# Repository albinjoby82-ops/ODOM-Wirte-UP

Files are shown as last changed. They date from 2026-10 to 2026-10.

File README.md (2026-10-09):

# ODOM POD Write-Up

The story of the ODOM POD: an ESP32-S3 odometry and localization pod that feeds pose to a VEX V5 brain over an RS-485 link.

This repo holds the narrative write-up. The operations team will turn it into a notebook, so each section is a self-contained, numbered document in `docs/`, meant to be read in order as one story.

## Reading order

| # | Section | Status |
|---|---|---|
| 1 | [Why These Components](docs/01-component-rationale.md) | Done |
| 2 | [What We Built on the Breadboard](docs/02-breadboard-firmware.md) | Done |
| 3 | [PCB V1](docs/03-pcb-v1.md) | Done |
| 4 | [PCB V2](docs/04-pcb-v2.md) | Done |

More sections will be added to this table as the story grows.

## What's in the repo

| Folder | What |
|---|---|
| [`docs/`](docs/) | The write-up, one numbered file per section, with images in `docs/img/` and clips in `docs/media/` |
| [`hardware/`](hardware/) | KiCad design files, Gerbers and PDFs for each PCB version |
| [`code/`](code/) | The pod firmware at each stage: breadboard, PCB V1 and PCB V2 |

## The story in one paragraph

The V5 brain is a good motor controller but a poor sensor platform. The ODOM POD moves sensing and pose estimation onto an ESP32-S3 and sends pose to the V5 as a pure sensor source. Motion control stays on the V5.

## Conventions

- One section per file in `docs/`, named `NN-short-title.md`, so the order is obvious and maps cleanly to notebook sections.
- Legality (VUR12) and latency points are woven into the relevant section, not split out.
- Figures and images go in `docs/img/` when they are added.

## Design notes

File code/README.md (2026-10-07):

# Firmware snapshots

The pod's ESP32-S3 firmware at three points in the project. Each folder is an exact copy of one commit. Nothing has been edited, so the commit hash tells you what you are looking at.

| Folder | Hardware | Commit | Written by |
|---|---|---|---|
| [`breadboard/`](breadboard/) | The breadboard build | `f9613c0` (Sep 12) | Ronan Hawkins |
| [`pcb-v1/`](pcb-v1/) | PCB V1 | `f138950` (Sep 30) | Ronan Hawkins |
| [`pcb-v2/`](pcb-v2/) | PCB V2 | `986a2f3` (Oct 6) | Ronan Hawkins and Albin Joby |

The commits are from [`ODOM-CODE`](https://github.com/albinjoby82-ops/ODOM-CODE), which has the same history as Ronan's [`gaelforce_esp32`](https://github.com/ronanhawkins/gaelforce_esp32). The V2 snapshot is the latest commit in `ODOM-CODE`. [Pull request 1](https://github.com/ronanhawkins/gaelforce_esp32/pull/1) holds the same work up to `d8f95ed`. V2 has not been tested on a built board.

What changed between them is mostly the pin numbers in `include/pod_config.hpp`. The V1 and V2 firmware are not interchangeable, so flash each one only on its own board.

Each folder builds with PlatformIO (ESP-IDF) for the ESP32-S3-DevKitC-1 with the N8R8 module. The shared `gflib` library (odometry, particle filter and link protocol) is not included here, because it is not in either source repo. It is expected next to the project as `../gflib`.

The ToF firmware image in `src/tof_firmware.cpp` comes from SparkFun's Qwiic TMF882X library. The source repos do not have a licence file.

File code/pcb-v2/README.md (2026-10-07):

# Gaelforce ESP32 pod (ODOM V2)

Firmware for an ESP32-S3 sensor pod that works out where the robot is on the
field. It drives nothing: it sends its pose estimate over RS-485 to the Brain.

It combines two quadrature tracking-wheel encoders, a BNO085 IMU and four
TMF8821 distance sensors in a particle filter (`gflib`), and reports the result
100 times a second.

Board: ESP32-S3-DevKitC-1 with an **N8R8** module. Built with PlatformIO and
ESP-IDF.

## Pin map (V2 PCB)

These are the pins the V2 PCB is wired to, and what `include/pod_config.hpp`
and `tools/tof_test` are set to. **8 pins moved from V1** (shown in bold below);
the full list with the reasons is in [PIN_CHANGES.md](PIN_CHANGES.md).

> **V1 and V2 firmware are not interchangeable.** GPIO1, 2 and 4 were encoder
> inputs on V1 and are ToF enable outputs on V2. Flash V2 firmware only on a V2
> board. V1 firmware is commit `f138950`.

| Function | Signal | V2 GPIO | V1 GPIO | Changed |
|---|---|---|---|---|
| Vertical encoder | A | **40** | 1 | yes |
| Vertical encoder | B | **42** | 2 | yes |
| Horizontal encoder | A | **39** | 3 | yes |
| Horizontal encoder | B | **41** | 4 | yes |
| IMU (BNO085) | RX | 8 | 8 | no |
| RS-485 | TX (DI) | 17 | 17 | no |
| RS-485 | RX (RO) | 18 | 18 | no |
| RS-485 | DE + RE (tied) | **7** | 21 | yes |
| ToF I2C | SDA (all 4) | 16 | 16 | no |
| ToF I2C | SCL (all 4) | 15 | 15 | no |
| ToF EN | FRONT | **4** | 11 | yes |
| ToF EN | RIGHT | 12 | 12 | no |
| ToF EN | REAR | **1** | 14 | yes |
| ToF EN | LEFT | **2** | 13 | yes |

Free for future use: 3 (strapping pin), 5, 6, 9, 10, 11, 13, 14, 21, 38.

### Pins that must not be used

On an N8R8 module:

| GPIO | Reason |
|---|---|
| 0, 45, 46 | strapping pins |
| 19, 20 | native USB (flashing and serial monitor) |
| 26-32 | SPI flash |
| 33-37 | octal PSRAM, wired inside the module even though this project leaves PSRAM off |
| 43, 44 | console UART |
| 48 | on-board RGB LED |

This is why the encoders went to 39-42 and not 35-38: 35, 36 and 37 are the
PSRAM pins.

## Wiring

### Encoders (via SN74LVC245A level converter)

The encoders connect to the A side of the converter and the ESP32 to the B side
(DIR tied high, OE to GND, VCC to 3.3 V). Each signal passes straight across
(A1 to B1 and so on). The B pins are arranged so the wiring is easy, not in the
order the firmware names them:

| Converter pin | Encoder wire | ESP32 GPIO |
|---|---|---|
| B1 | Vertical **B** | 42 |
| B2 | Horizontal **B** | 41 |
| B3 | Vertical **A** | 40 |
| B4 | Horizontal **A** | 39 |

Tie unused converter inputs to GND. If an encoder counts backwards, flip its
`kVertReversed` / `kHorizReversed` flag in `pod_config.hpp` rather than
rewiring.

### IMU (BNO085, UART-RVC mode)

| IMU pin | Connects to |
|---|---|
| SDA (becomes the IMU's serial TX in UART mode) | GPIO8 |
| SCL | nothing |
| VIN | 3.3 V |
| GND | GND |

The **P0 jumper must be bridged** to select UART-RVC mode. Without it the IMU
starts in I2C mode and GPIO8 never receives anything.

### RS-485 link to the Brain (SP3485)

| SP3485 pin | Connects to |
|---|---|
| DI | GPIO17 |
| RO | GPIO18 |
| DE and RE, tied together | GPIO7 |
| VCC / GND | 3.3 V / GND |
| A, B | the Brain's A, B |

Run a **ground wire** to the Brain alongside A and B. If the link only receives
garbage, A and B are probably swapped. DE is the talk/listen switch: the ESP32
switches it automatically around each message, so it must not be shared with
anything else.

### ToF sensors (4x TMF8821)

All four share SDA and SCL, are powered from **3.3 V**, and each has its own EN
pin because they all start at the same I2C address and are brought up one at a
time. Leave INT, GPIO0 and GPIO1 on the sensor boards unconnected.

The breakouts' own pull-up resistors are the only pull-ups on the bus, so at
least one breakout's I2C pull-up jumper must be closed.

## Changing a pin

Every pin lives in `include/pod_config.hpp`. The ToF bench test keeps its own
copy of the ToF pins in `tools/tof_test/src/main.cpp`, so change both. See
[PIN_CHANGES.md](PIN_CHANGES.md) for the history of each move.

## Bench test for the ToF sensors

`tools/tof_test` is a standalone project that brings up the four sensors with
the pod's own driver and prints one distance per sensor. It does not need
`gflib`.

```bash
pio run -d tools/tof_test -t upload -t monitor
```

It prints `FRONT`, `RIGHT`, `REAR` and `LEFT` distances in mm. `--` means
nothing is in range, `DEAD` means a sensor failed to start, and `STALLED` means
it stopped sending results. A reading that sticks at 20-60 mm and never changes
means something is right against the lens.

## Building the pod firmware

The pod firmware needs `gflib` (particle filter, odometry and link framing)
cloned next to this repo at `../gflib`; it is not in this repository.

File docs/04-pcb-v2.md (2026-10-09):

# PCB V2

V2 fixes what went wrong with V1. It has two changes: a fixed IMU ground, and a pin map that follows where the cables leave the board.

## What changed

**The IMU ground.** On V1, the ground trace for the IMU was on the top layer when it should have been on the bottom. V2 has it on the bottom layer.

**The pins.** V1 kept the breadboard's pin numbers, which left the encoder and ToF cables scattered around the board. V2 regroups the pins so each set of cables leaves from one place. Eight pins moved. Everything else is the same.

| Signal | V1 GPIO | V2 GPIO | Why |
|---|---|---|---|
| Vertical encoder A | 1 | **40** | Encoders grouped on four adjacent header pins |
| Vertical encoder B | 2 | **42** | |
| Horizontal encoder A | 3 | **39** | |
| Horizontal encoder B | 4 | **41** | |
| ToF enable, front | 11 | **4** | Uses a pin the encoders freed up |
| ToF enable, rear | 14 | **1** | Uses a pin the encoders freed up |
| ToF enable, left | 13 | **2** | Uses a pin the encoders freed up |
| RS-485 DE/RE | 21 | **7** | Nearest free pin that is not a strapping pin |

These stay the same: the IMU receive pin on GPIO 8, RS-485 TX and RX on 17 and 18, I²C SDA and SCL on 16 and 15, and the right ToF enable on 12.

The level converter's B pins are also wired to make the cabling easier. B1 and B2 carry the encoders' B channels, and B3 and B4 carry their A channels. If an encoder counts backwards, the firmware has a reverse flag for each one, so the wiring does not need to change.

The full write-up of every move, with the reason for each, is in [`PIN_CHANGES.md`](../code/pcb-v2/PIN_CHANGES.md), and the V2 wiring tables are in the [firmware README](../code/pcb-v2/README.md).

## The V2 firmware

The V2 firmware is the V1 firmware with the new pin numbers in `include/pod_config.hpp`, plus the later ToF mask-order fix and bench test. It is in [`code/pcb-v2/`](../code/pcb-v2/), at commit `986a2f3` of `ODOM-CODE`.

V1 and V2 firmware are not interchangeable. GPIO 1, 2 and 4 were encoder inputs on V1 and are ToF enable outputs on V2, so flashing the wrong firmware drives the wrong wire. Flash V2 firmware only on a V2 board.

## Status

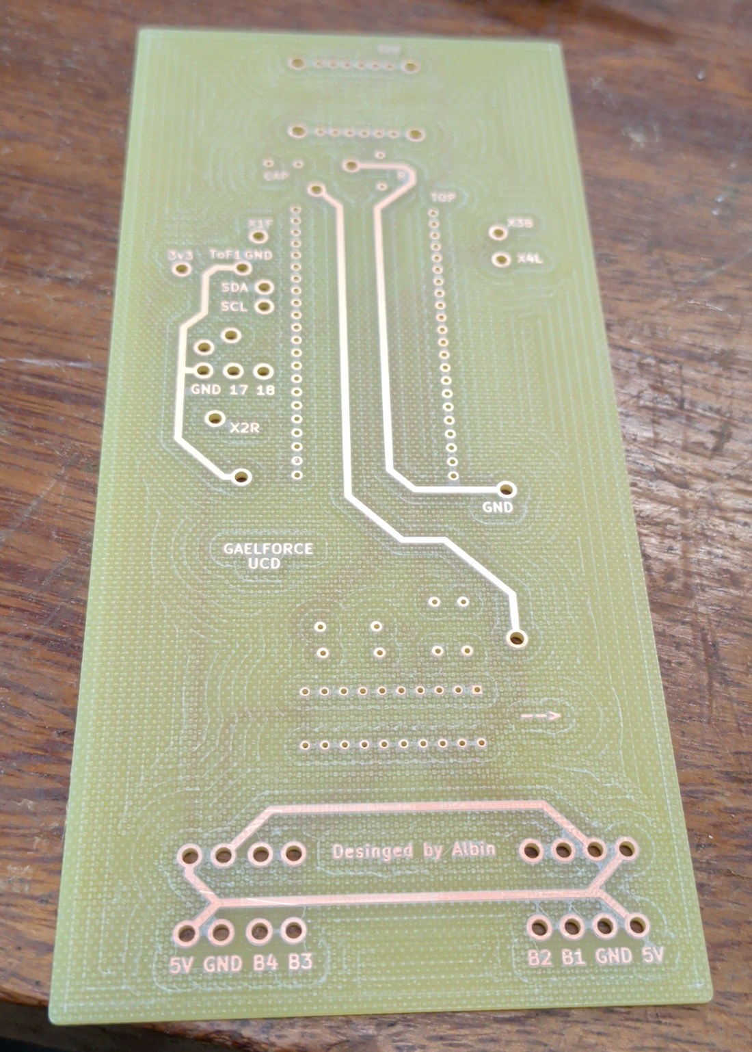
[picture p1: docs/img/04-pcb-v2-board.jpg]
The bare V2 board, a tall narrow green board with white copper traces and silkscreen labels such as 5V, GND, B4 and B3 along the bottom


The V2 board right after it came off the machine at the Elecworkshop.

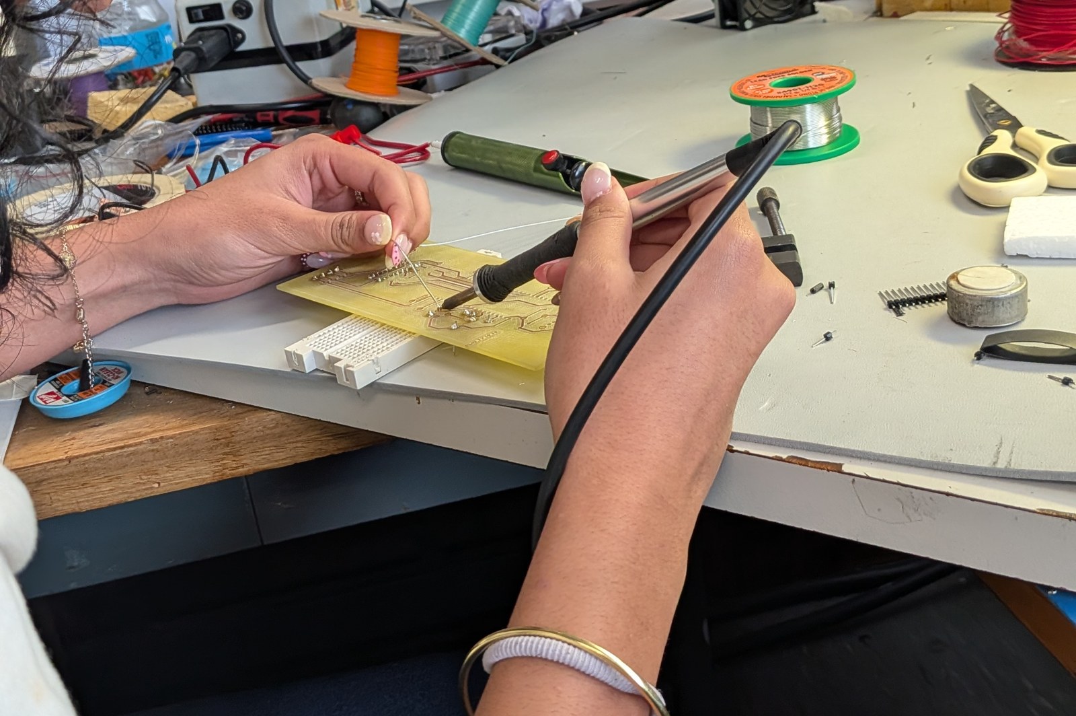
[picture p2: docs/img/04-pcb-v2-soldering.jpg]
Two people soldering parts onto a V2 board held on a breadboard strip, one holding a part in place and the other using a soldering iron


Soldering the V2 board with Selma. The board is now soldered and finished. It is waiting to be tested, so there are no results here.

## Design files

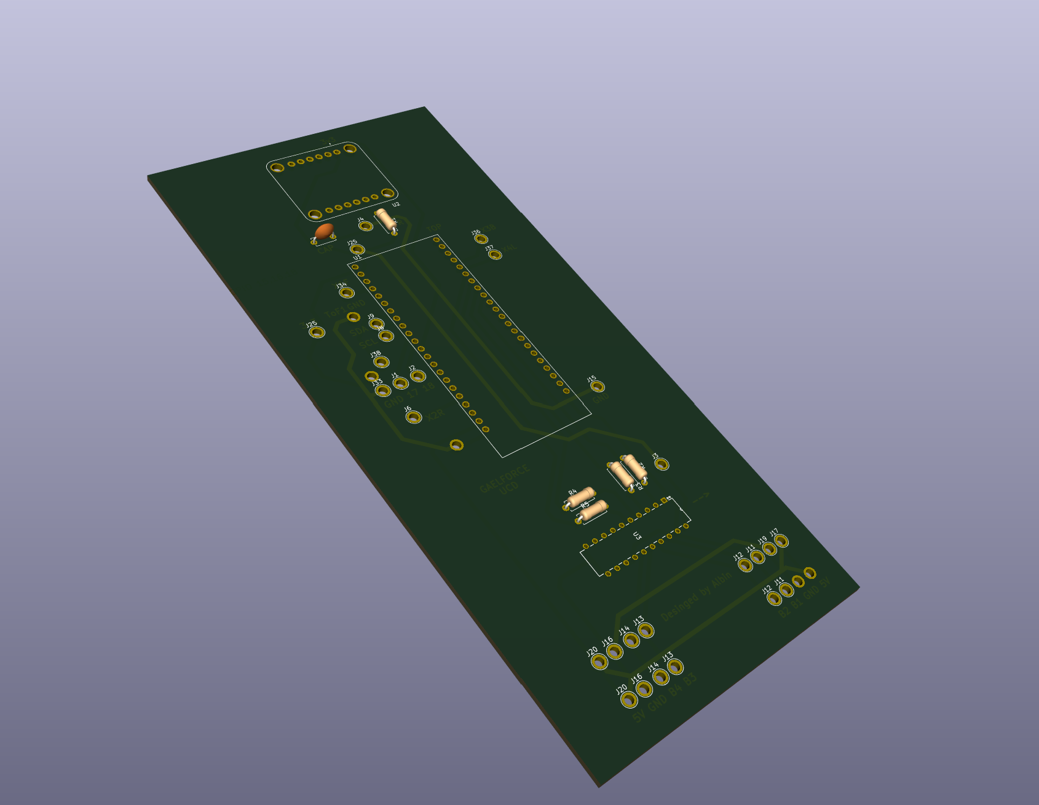
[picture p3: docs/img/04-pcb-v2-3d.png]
A 3D render of the V2 board from KiCad: a tall green board with the IMU breakout outline at the top, the ESP32-S3 outline in the middle, four resistors and the level converter below it, and rows of single-pin connectors at the bottom and along the sides


A 3D render of the V2 board from KiCad. The board is long and narrow. The IMU breakout is at the top, the ESP32-S3 is in the middle, and the four resistors and the level converter are below it. The ESP32-S3 and the IMU show only as outlines, because their 3D models are not in the project.

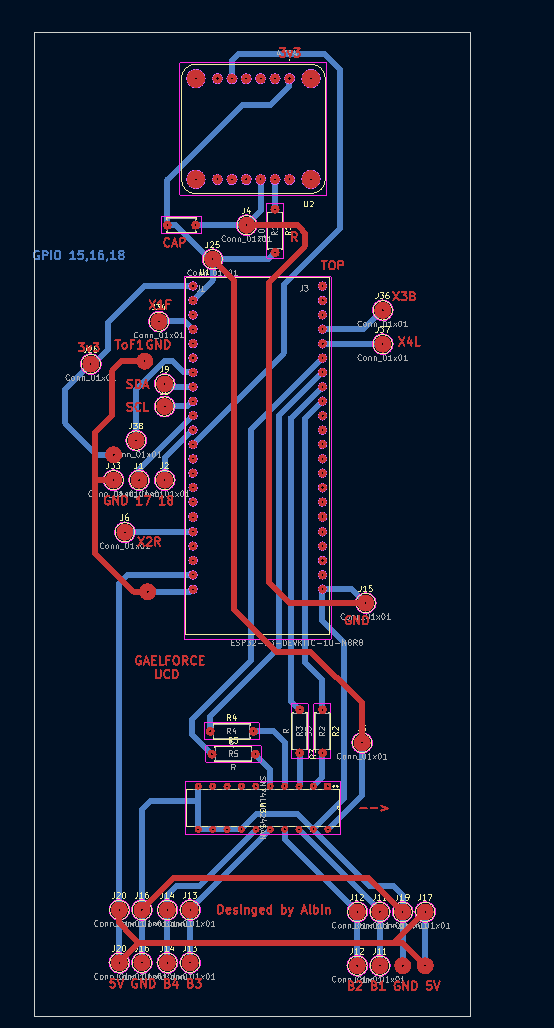
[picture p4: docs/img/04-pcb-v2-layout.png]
The V2 board layout in KiCad, front copper in red and back copper in blue, with traces running from the ESP32-S3 pins to single-pin connectors at the bottom and along the sides


The V2 board layout, from the KiCad PCB editor. Front copper is red and back copper is blue. Traces run from the ESP32-S3 pins and the level converter to the single-pin connectors at the bottom and along the sides. Click the image for the PDF.

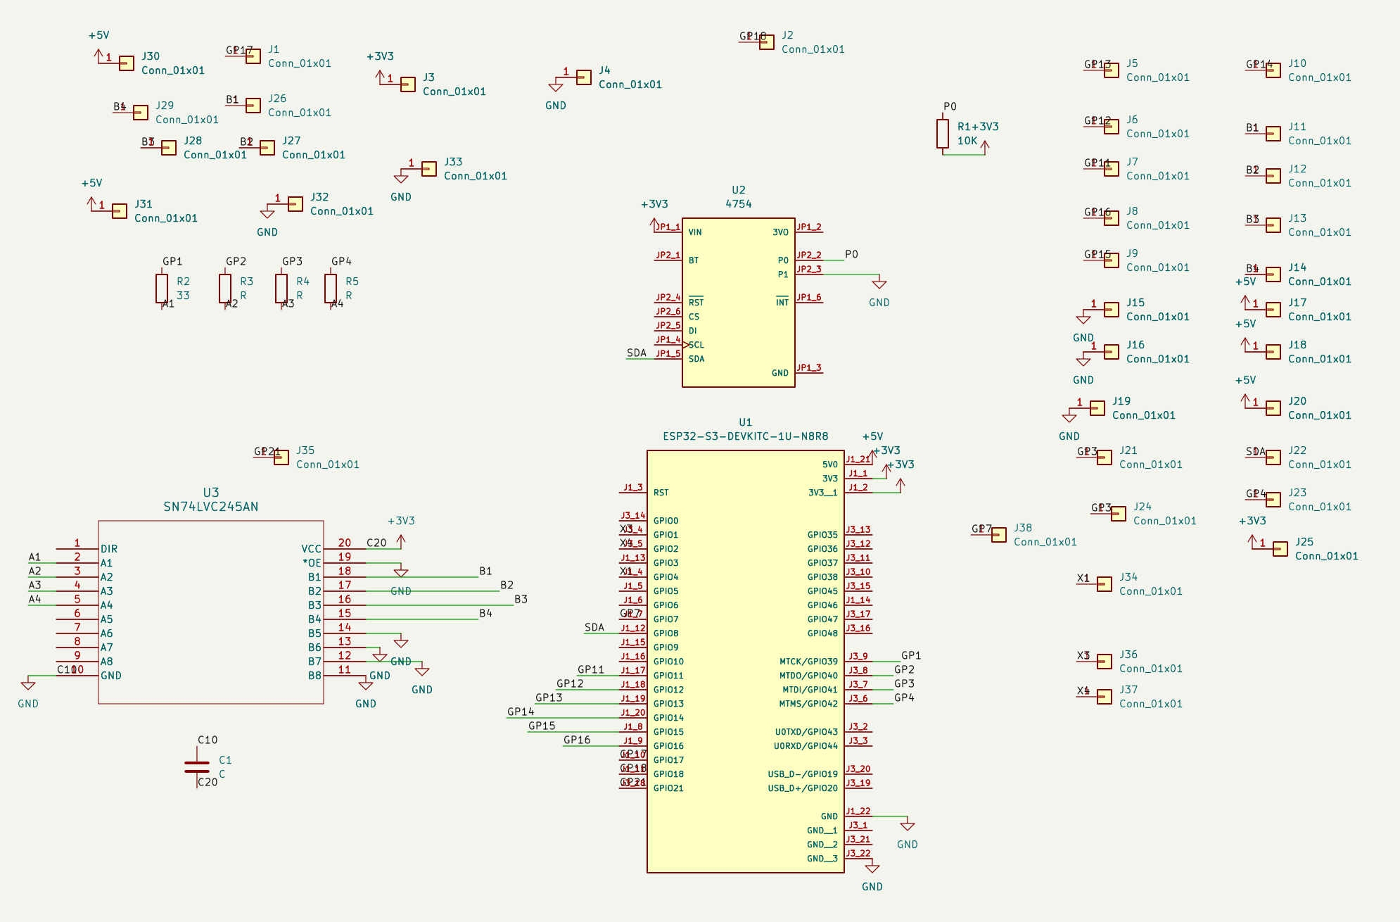
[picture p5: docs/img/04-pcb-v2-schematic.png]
The V2 schematic: the ESP32-S3 dev board, the IMU breakout, the level converter with four resistors, and a column of single-pin connectors on the right


The V2 schematic. It has the ESP32-S3 dev board, the IMU breakout, the level converter and four resistors, and a single-pin connector for each off-board wire. Click the image for the PDF.

- [Schematic (PDF)](../hardware/v2/ODOM-V2-schematic.pdf)
- [PCB layout (PDF)](../hardware/v2/ODOM-V2-pcb-layout.pdf)
- [Gerbers and drill files](../hardware/v2/gerbers.zip), as sent to the board maker. The [job file](../hardware/v2/ODOM%20V2-job.gbrjob) is next to it.
- [KiCad project folder](../hardware/v2/): the schematic, board file, project file and custom symbol and footprint libraries.

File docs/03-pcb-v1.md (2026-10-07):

# PCB V1

## The idea

The breadboard worked, so the first PCB was a direct copy of it: the same schematic, the same parts and the same connections, laid out on a board. The schematic and the PCB were designed in KiCad, the board was made in the Elecworkshop, and the parts were soldered on.

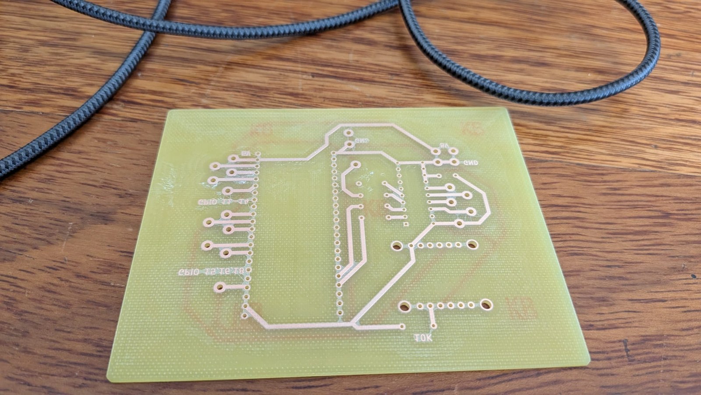
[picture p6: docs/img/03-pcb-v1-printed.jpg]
The bare V1 board after it was made, copper side, with the pin labels printed mirrored


The bare V1 board, copper side.

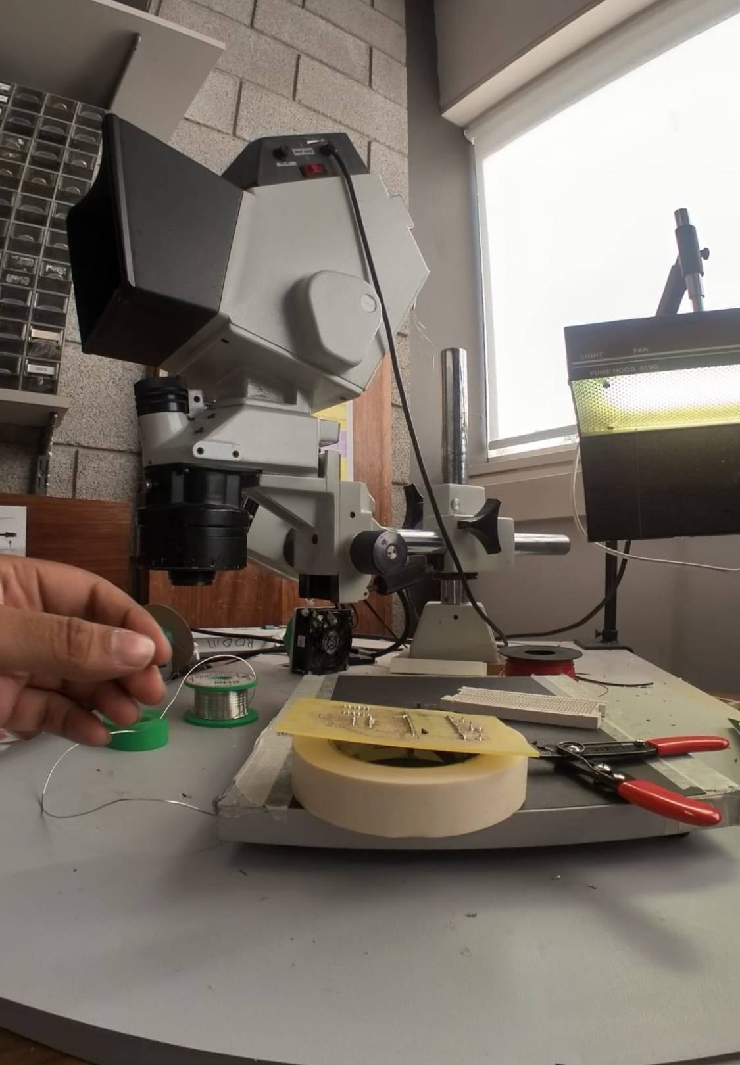
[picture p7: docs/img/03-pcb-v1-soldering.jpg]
Soldering parts onto the V1 board at a workbench with a microscope, solder and wire cutters


Soldering the V1 board.

## What went wrong

On a breadboard, any signal can go to any pin, because you just plug in a jumper wire. On a PCB that freedom is gone, and the wiring that matters is the wiring that leaves the board. Both encoders and all four ToF sensors connect to the pod by cables, so every one of those cables had to leave the board somewhere.

The pin assignments came straight from the breadboard, where they had been chosen for convenience, so on the PCB they ended up scattered across the ESP32's headers. The cables coming off the board for the encoders and the ToF sensors were a tangled mess.

Copying the breadboard exactly turned out not to be the right way to get a PCB. A good PCB layout starts from where the connectors and cables go, and picks the pins to suit.

## What worked

The board worked. The ToF sensors and the rest of the pod ran the V1 firmware. There was one layout mistake: the ground trace for the IMU was on the top layer when it should have been on the bottom. V2 fixes it.

## The V1 firmware

The V1 firmware is Ronan's `gaelforce_esp32` at commit [`f138950`](https://github.com/albinjoby82-ops/ODOM-CODE/tree/f138950) (Sep 30, "pin changes"). A copy is in this repo at [`code/pcb-v1/`](../code/pcb-v1/). It differs from the breadboard firmware in the pin numbers only. Two signals moved: the horizontal encoder from GPIO 4/5 to GPIO 3/4, and the ToF I²C pins from SDA/SCL 15/16 to 16/15.

| Function | Signal | GPIO |
|---|---|---|
| Vertical encoder | A / B | 1 / 2 |
| Horizontal encoder | A / B | 3 / 4 |
| IMU (BNO085) | RX | 8 |
| RS-485 | TX / RX / DE+RE | 17 / 18 / 21 |
| ToF I²C | SDA / SCL | 16 / 15 |
| ToF enable | Front / Right / Rear / Left | 11 / 12 / 14 / 13 |

## What it taught us

The problem was never the parts or the schematic. It was the pin layout. That led to V2, which starts from where the cables leave the board and groups the pins to match.

## Design files

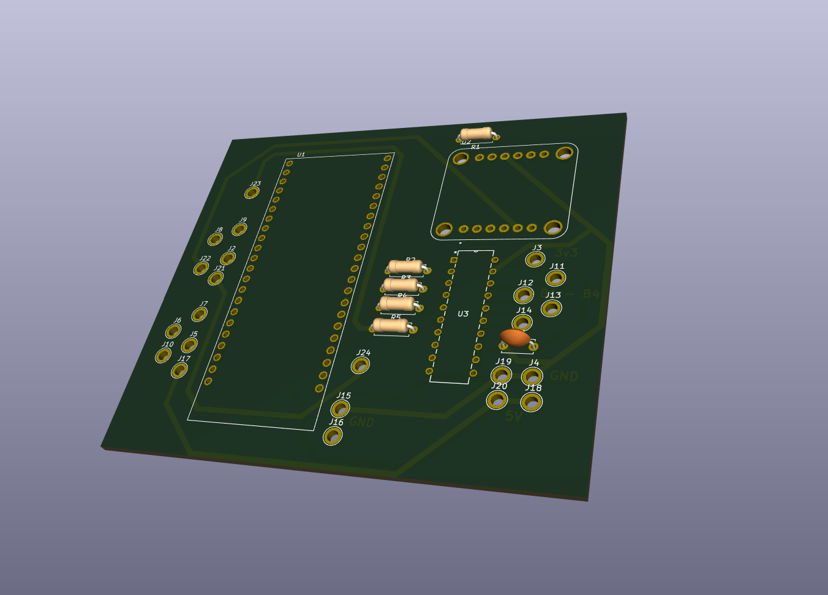
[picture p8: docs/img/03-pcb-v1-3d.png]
A 3D render of the V1 board from KiCad: the ESP32-S3 dev board footprint on the left, the IMU breakout at the top right, the level converter and four resistors in the middle, and single-pin connectors around the edges


A 3D render of the V1 board from KiCad. The ESP32-S3 dev board sits on the left, the IMU breakout at the top right, and the level converter and the four series resistors in the middle. The single-pin connectors are scattered around the edges and the corners.

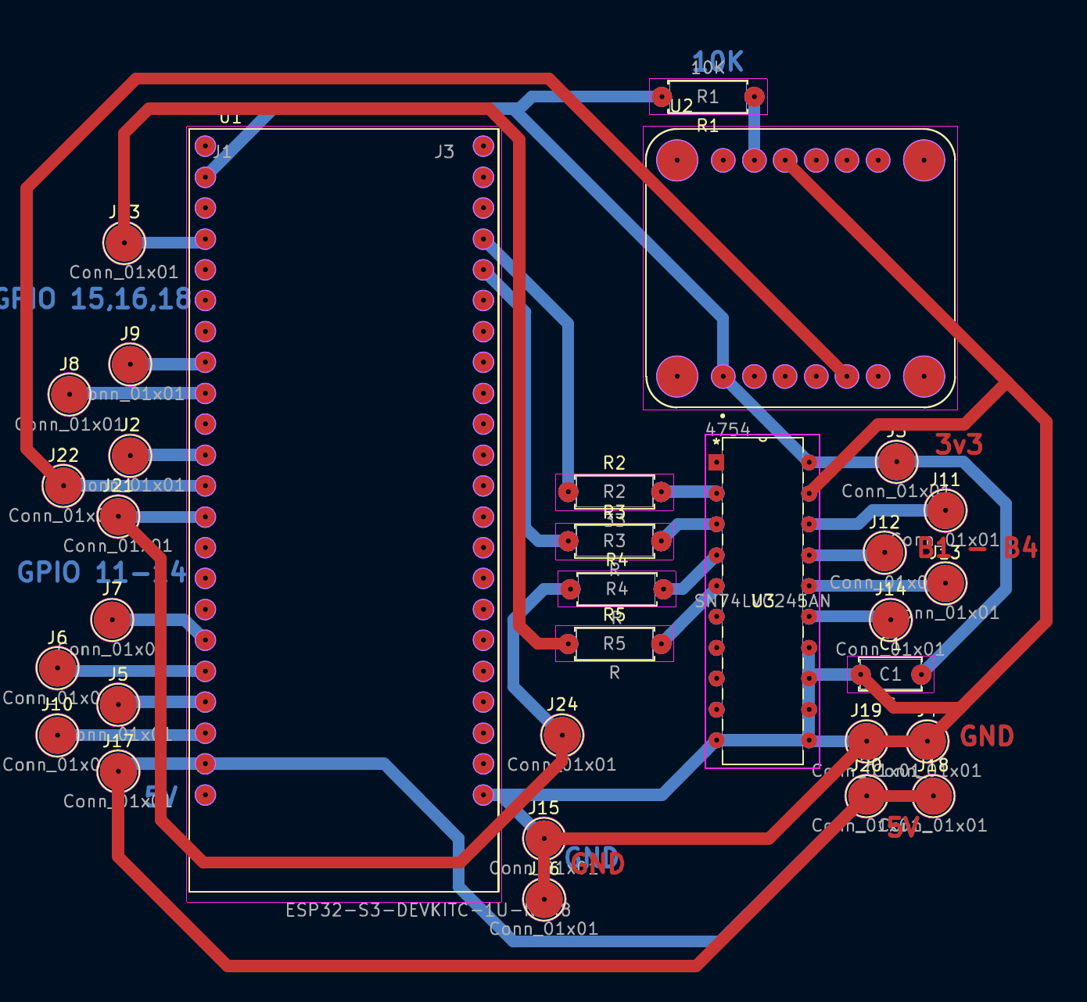
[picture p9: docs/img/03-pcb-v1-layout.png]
The V1 board layout in KiCad, front copper in red and back copper in blue, with traces from the ESP32-S3 pins running out to single-pin connectors around the edges


The V1 board layout, from the KiCad PCB editor. Front copper is red and back copper is blue. The traces fan out from the ESP32-S3's pins to the single-pin connectors around the edges. Click the image for the PDF.

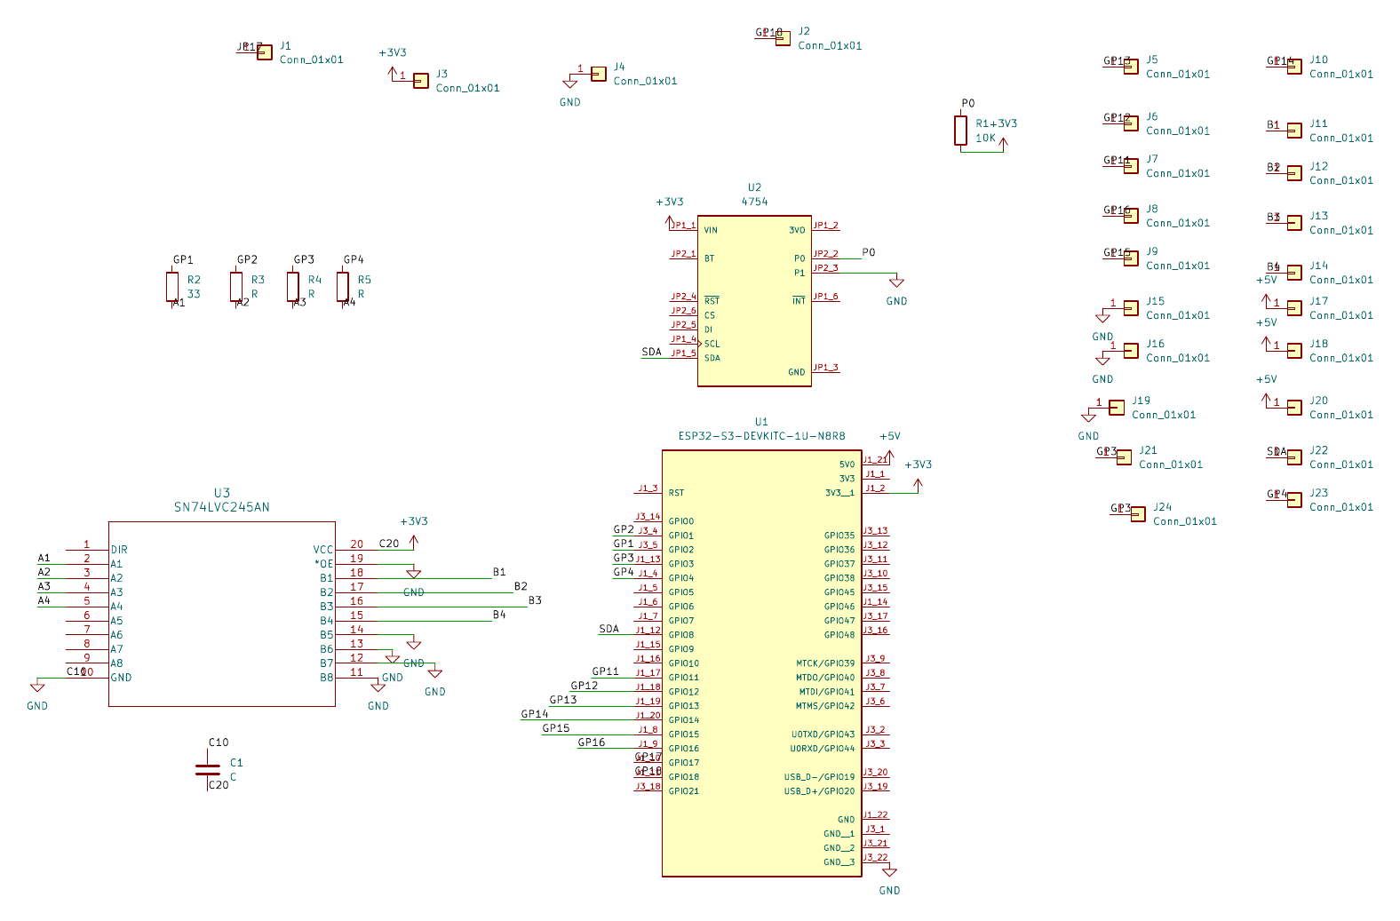
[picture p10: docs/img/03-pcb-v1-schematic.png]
The V1 schematic: the ESP32-S3 dev board, a level converter with series resistors on the four encoder lines, the IMU breakout, and single-pin connectors for the off-board wires


The V1 schematic. It has the ESP32-S3 dev board, the level converter with series resistors on the four encoder lines, the IMU breakout, and a single-pin connector for each off-board wire. Click the image for the PDF.

- [Schematic (PDF)](../hardware/v1/ODOM-V1-schematic.pdf)
- [PCB layout (PDF)](../hardware/v1/ODOM-V1-pcb-layout.pdf)
- [Gerbers and drill files](../hardware/v1/gerbers.zip), as sent to the board maker.
- [KiCad project folder](../hardware/v1/): the schematic, project file and custom symbol and footprint libraries.

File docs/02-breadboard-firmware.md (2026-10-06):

# What We Built on the Breadboard

When the parts arrived, we wired every component from section 1 onto a breadboard and flashed one firmware image to the ESP32-S3.

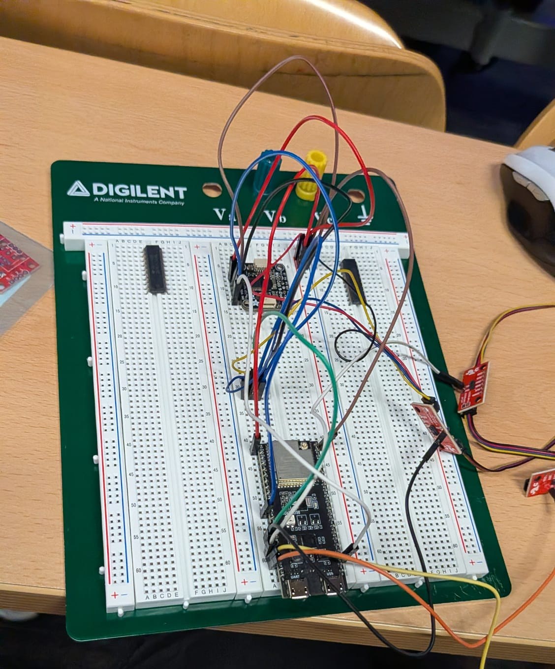
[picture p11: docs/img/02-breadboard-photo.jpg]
The breadboard: an ESP32-S3 dev board in the centre, a level converter and the BNO085 across the top, and ToF sensors on Qwiic cables off the right edge


The breadboard build. The ToF sensors sit off the board on their Qwiic cables.

## What it does

The firmware reads the two AMT102-V encoders (through the level converter), the BNO085 IMU, and the four TMF8821 ToF sensors. It runs a 300-particle Monte Carlo localization filter and sends the resulting pose to the V5 brain over RS-485 every 10 ms (100 Hz). The brain replies with its status, and the pod uses that reply to measure round-trip time and to stop trusting ToF readings while the robot is driving hard. The pod drives nothing. It only reports pose.

Everything runs in a single task, and the firmware prints its own timing, link and per-sensor diagnostics about once a second.

## Pin map (breadboard)

| Function | Signal | GPIO |
|---|---|---|
| Vertical encoder | A | 1 |
| Vertical encoder | B | 2 |
| Horizontal encoder | A | 4 |
| Horizontal encoder | B | 5 |
| IMU (BNO085, UART-RVC) | RX | 8 |
| RS-485 | TX (DI) | 17 |
| RS-485 | RX (RO) | 18 |
| RS-485 | DE + RE (tied) | 21 |
| ToF I²C (all 4 sensors) | SDA | 15 |
| ToF I²C (all 4 sensors) | SCL | 16 |
| ToF enable | Front | 11 |
| ToF enable | Right | 12 |
| ToF enable | Rear | 14 |
| ToF enable | Left | 13 |
| Console UART | TX / RX | 43 / 44 (921600 baud) |

Notes on the wiring:
- The encoders' 5 V outputs go through the SN74LVC245A level converter to reach 3.3 V logic.
- The SP3485 RS-485 transceiver has DE and RE tied together and driven as the UART's RTS pin, so the hardware handles the send/receive turnaround.
- The BNO085 is receive-only. Its P0 jumper must be bridged to select UART-RVC mode, otherwise it starts in I²C mode and the RX pin stays silent.
- The four ToF sensors share one I²C bus. They all boot at address `0x41`, so each has its own enable pin and is moved to `0x42` (front), `0x43` (right), `0x44` (rear) or `0x45` (left) one at a time at boot.
- The ToF enable pins are in harness order, not numeric order.
- GPIO 0/45/46, 19/20, 26-37 and 48 are not used on this module (strapping, USB, flash, PSRAM and the on-board LED).

## Circuit diagrams

The breadboard was wired from these four diagrams.

### Encoders

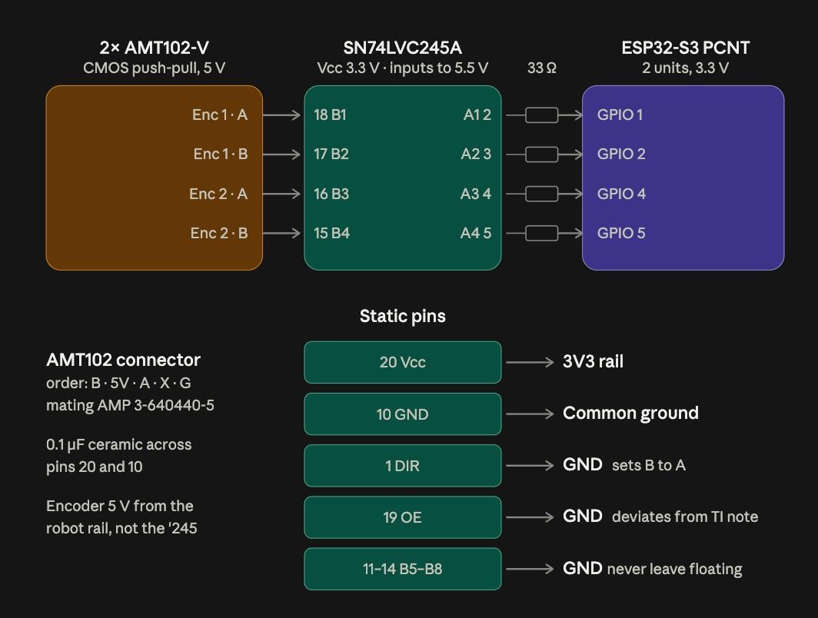
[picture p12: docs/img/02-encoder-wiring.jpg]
Two AMT102-V encoders into an SN74LVC245A level converter, through 33 ohm resistors, to four ESP32-S3 GPIOs


The 5 V encoder outputs go through the SN74LVC245A to 3.3 V logic, with a 33 Ω resistor in each line. The encoders get their 5 V from the robot rail, not from the level converter. The unused B5-B8 inputs are tied to ground, and OE is tied low.

### IMU

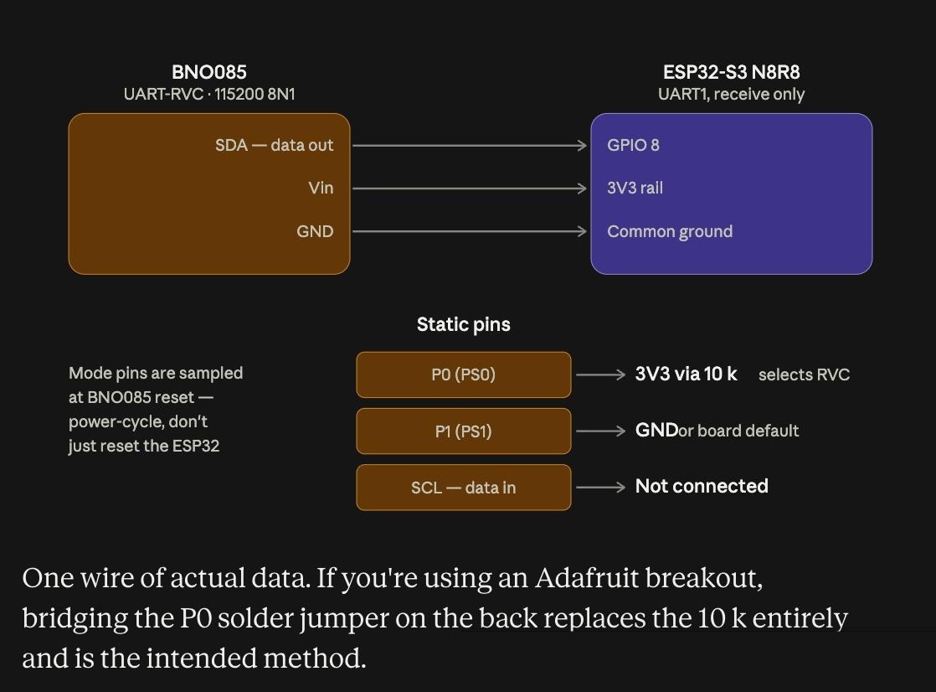
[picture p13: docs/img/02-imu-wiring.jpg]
BNO085 in UART-RVC mode wired to ESP32-S3 GPIO 8, with its mode pins tied off


One data wire from the BNO085 to GPIO 8, plus power and ground. P0 selects RVC mode, so it is tied to 3.3 V, or bridged with the solder jumper on the back of the Adafruit breakout. The mode pins are only read at reset, so the BNO085 has to be power-cycled, not just the ESP32.

### ToF sensors

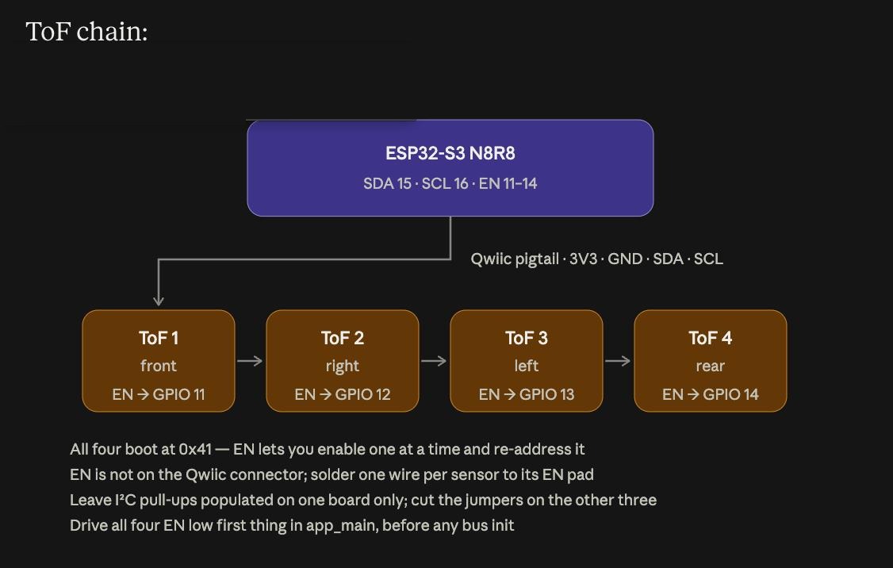
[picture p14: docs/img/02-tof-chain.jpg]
Four TMF8821 sensors daisy-chained over Qwiic from the ESP32-S3, each with its own enable line


Four TMF8821s on one Qwiic chain, each with its own enable wire (front, right, left, rear on GPIO 11, 12, 13, 14). All four boot at `0x41`, so they are enabled one at a time and given new addresses. The enable pin is not on the Qwiic connector, so one wire is soldered to each sensor's EN pad. I²C pull-ups are left on for one board only. All four sensors worked on the breadboard with this firmware.

### RS-485 link

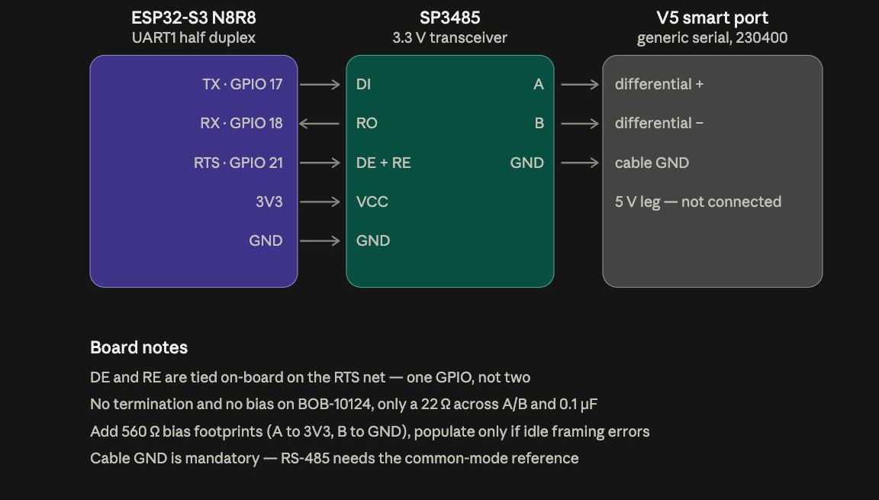
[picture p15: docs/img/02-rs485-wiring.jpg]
ESP32-S3 to SP3485 transceiver to the V5 smart port, with board notes on termination and bias


The ESP32's UART drives an SP3485 transceiver, which connects to the V5 smart port's two differential lines. The 5 V line on the smart port is not connected, but the cable ground is, because RS-485 needs the common reference.

### Working on it

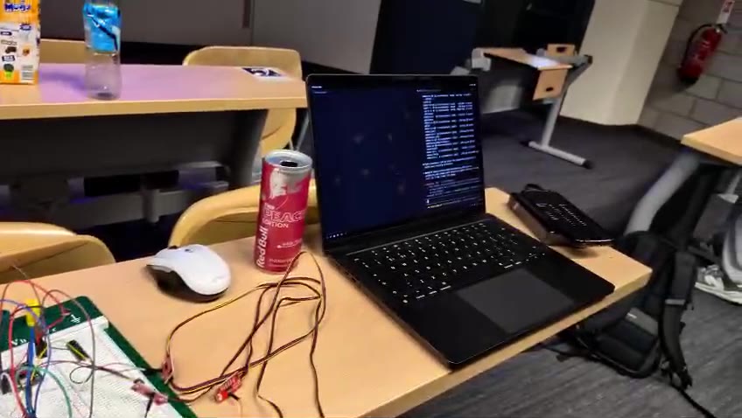
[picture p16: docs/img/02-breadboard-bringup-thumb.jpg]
Firmware console output on the laptop beside the breadboard


A 5-second clip of the breadboard being worked on, with the firmware's console output on the laptop. Click the image to play it.

## Key settings

| Setting | Value |
|---|---|
| Encoder resolution | 8192 counts per revolution (AMT102-V at 2048 PPR, all four edges counted) |
| Encoder glitch filter | 1 µs |
| Pod mounting | Diamond, 45° |
| IMU link | 115200 baud, 19-byte frames |
| Loop rate | 10 ms (100 Hz) |
| ToF I²C speed | 100 kHz to set up, 400 kHz to run |
| ToF ranging | 70 ms period, staggered 17 ms between sensors, custom 4-zone map |
| Particle filter | 300 particles |
| Pose report | 56 bytes from the pod, 23-byte status reply from the brain |

## The code we flashed

| What | Where |
|---|---|
| Firmware | [`ODOM-CODE` at `f9613c0`](https://github.com/albinjoby82-ops/ODOM-CODE/tree/f9613c0) (Ronan Hawkins, Sep 12) |
| Same code, original repo | [`gaelforce_esp32` at `f9613c0`](https://github.com/ronanhawkins/gaelforce_esp32/tree/f9613c0) |
| Copy in this repo | [`code/breadboard/`](../code/breadboard/) |
| Pin numbers | `include/pod_config.hpp` |
| Main loop | `src/main.cpp` |
| ToF bring-up and filtering | `src/tof_array.cpp` |
| ToF SPAD mask | `tools/tmf8x2x_gaelforce_mask.c` |

Build with PlatformIO (ESP-IDF) for the ESP32-S3-DevKitC-1 with the N8R8 module. The shared `gflib` library (odometry, particle filter, link protocol) is not in either repo.

Later commits are not part of the breadboard build. `f138950` (Sep 30) moved the pins, `5a9fc94` (Oct 1) fixed the ToF mask download order and added a ToF bench test, and the V2 PCB rework came after that.

## How it differs from section 1

Section 1 is the design intent. The breadboard build runs as one task at 100 Hz rather than the two-core split, leaves PSRAM off, and gives the filter one median distance per ToF sensor rather than a distance-and-angle pair.

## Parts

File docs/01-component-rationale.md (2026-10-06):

# Why These Components

## The Core Decision: Sensing on an ESP32-S3, Motion Control on the V5

Every choice in this pod traces back to one split: sensing lives on an ESP32-S3, motion control stays on the V5 brain.

The V5 simply can't host these sensors well. Smart ports run a closed RS-485 protocol, the brain exposes no user I²C/SPI/UART for a BNO085 or TMF8821s, and the ADI 3-wire quadrature path was designed around 360 CPR encoders; it drops counts once you're running 8192 CPR. Even where the brain *can* read a sensor, the read itself is a problem: smart-port devices are polled on the same bus as motor commands, with a 10 ms default and a 5 ms floor, so the data a controller sees is stale and jittery by the time it arrives. On the ESP32, an encoder read is a direct register access, the IMU is a timestamped 100 Hz stream, and dt is known exactly rather than inferred.

That precision needs somewhere to run without interference. Core 0 on the ESP32 handles all I/O; Core 1 runs the math, including 200 Hz MCL prediction, with nothing from the PROS scheduler competing for cycles. That two-core split is the design intent. The first breadboard build runs everything in one task at 100 Hz, which was enough to prove the sensors and the link.

None of this makes the V5 obsolete as a pose source. It was never one. The brain carries no IMU and no tracking encoders of its own. `LinkPoseSource` is its only pose source, and the custom PROS motion code consumes it through `IPoseSource`, which is why `runMotion` gates on `healthy()`, staleness, and `bootId`, because it has to assume the link can go bad.

Motion control itself stays on the V5 regardless, for two reasons that aren't up for debate: motors must be VEX, and you never put a network link inside a feedback loop. The ESP32 is a pose source, full stop. It never touches a motor command.

It's worth being honest about what this buys and doesn't buy. End-to-end latency over the link is roughly at parity with just reading native V5 sensors over the smart port (about 13 ms mean / 26 ms tail in the 460800 baud / 200 Hz analysis). The real advantage isn't speed, it's determinism: synchronous sampling, timestampable delay, and access to sensors the brain physically cannot read. And it's legal: VUR12 explicitly allows external electronics and non-VEX sensors.

## Why the ESP32-S3 Specifically

The S3 has hardware quadrature decoding (PCNT) and two cores that map directly onto the I/O / math split the design needs. It also brings three UARTs (console, BNO085, RS-485), ESP-IDF/FreeRTOS, and comes as a cheap, compact module, with no exotic sourcing. The N8R8 module has 8 MB of PSRAM, but the build leaves it off: the particle filter is only about 19 KB and runs faster in internal SRAM.

The alternatives were rejected for concrete reasons, not vibes:

- **Raspberry Pi (Linux):** scheduler jitter, and no hardware quadrature decoder.
- **AVR Arduino:** interrupt-based counting, software float, too little RAM.
- **Teensy 4.1:** a genuinely better encoder peripheral, but single-core, and a costly rewrite for a problem that isn't currently compute-bound.
- **RT1170:** best on paper, but there's no board suitable for a competition robot.

The ESP32-P4 is the upgrade path if compute ever does become the limiting factor.

Two liabilities come with the choice and need to stay visible: PCNT is 16-bit, so it wraps roughly every 4 revolutions at 8192 CPR, so the overflow ISR has to be high-priority and sanity-checked. And there's no double-precision FPU, so accidental doubles in the math path are a real failure mode, not a style nitpick.

## Encoders: 2× AMT102-V

These give 8192 CPR (2048 PPR × 4), which on a 2.75" wheel works out to roughly 0.027 mm/count, against 0.054 mm for the V5 Rotation Sensor and 0.61 mm for the ADI optical encoder.

But resolution isn't actually the win here. Both smart-sensor options already sit far below the real error floor of the system, so squeezing more counts out of them wouldn't move the needle. The real win is zero transport delay versus smart-port polling, and that win only exists because the encoders go through the ESP32. Wired into ADI ports instead, they'd have to be throttled to 96 PPR, which throws away the entire reason for buying them in the first place.

The trade-off worth naming: these are incremental encoders, with no absolute position across power cycles. That's fine here, because pose is seeded via `SET_POSE` at the start, not recovered from the encoders themselves. Their 5 V outputs go through an SN74LVC245 buffer to bring them down to 3.3 V logic. The physical setup is two-pod diamond odometry, with heading supplied separately by the IMU.

## IMU: BNO085 in UART-RVC Mode

The deciding factor is bias handling under the specific usage pattern of this robot. The BNO085's SH-2 firmware re-estimates gyro bias whenever the robot is stationary, and this robot stops every couple of seconds, so it gets frequent bias refreshes for free. The V5's own IMU, by contrast, calibrates once at init and then runs open-loop as it warms up, with no further correction. Since heading error couples directly into position error, that difference matters more than raw sensor specs.

Timing tells the same story: the BNO085 free-runs at 100 Hz and the ESP32 timestamps every frame, versus a polled V5 IMU with jitter that's never observable from outside.

It also just survives the sport better: it holds up under hard impacts in a way the V5 IMU doesn't.

RVC mode specifically was chosen because it sends unsolicited 19-byte frames at 115200 baud with no host protocol overhead, and critically, it doesn't share the I²C bus with the ToF sensors, which keeps the IMU's timing clean and independent of whatever the ToF chain is doing.

Two wiring details are deliberate, not incidental: PS0 is tied to the rail via the breakout's own solder jumper rather than a GPIO, to avoid a power-sequencing race; RST goes to GPIO 38 so firmware can re-latch the mode if needed.

Two parts rejected on paper, not in practice: the ICM-42688-P and ADIS16505 both have better raw bias stability than the BNO085, but neither has onboard sensor fusion. Given how often this robot stops, which is exactly where the BNO085's SH-2 fusion shines, the plan is to keep the BNO085 and add zero-velocity updates (ZUPTs) on top, rather than chase raw IMU specs that don't matter as much for this usage pattern.

## ToF: 4× TMF8821

These exist to bound odometry drift by giving the MCL filter absolute corrections. Odometry alone only ever gets worse over time, and something has to anchor it back to ground truth.

Multizone sensing specifically matters because a single TMF8821 yields both perpendicular distance *and* wall angle from one reading. That angle constrains heading directly, which is exactly what's needed to hit the ±2° target, but it only works if the zones are pre-processed into a (distance, angle) pair before they reach the filter; feeding raw zones in as independent measurements breaks the math.

One sensor faces each direction (front, right, rear, left), so some wall is visible from almost anywhere on the field, and they're staggered at 90° phase offsets to smooth corrections over time and spread CPU load rather than hitting all four at once.

These sensors are at their best near walls at close-to-normal incidence, which happens to be exactly where Gate 2 is measured. They have no moving parts to take hits, and each reading is a single snapshot with no scan skew to correct for.

The known weaknesses are real and worth stating plainly: each zone covers roughly 10°, so readings start blending in clutter at range; readings are biased at oblique angles; and the sensor only delivers about 15 Hz in 4×4 mode. A 2D lidar (LD06 / STL-27L) is the fallback, but only gets pulled in if the characterization matrix actually fails. It's not a parallel-track option.

## The RS-485 Link

The smart port is physically RS-485 under the hood, so the ESP32 side uses an SP3485 half-duplex transceiver with hardware DE/RE control to match it. The brain stays bus master throughout, using request/response framing specifically to avoid bus contention.

The link runs at 230400 baud rather than the 460800 the latency-parity analysis assumed, because the V5's oscillator carries roughly 1.5% error at 460800 against a 2–3% total error budget, which is not enough margin to run that fast safely. `kLinkBaud` lives in `link.hpp` as the single source of truth for this, so it's worth flagging that the latency numbers quoted above were measured at 460800 and should be re-run at 230400 to confirm they still hold.

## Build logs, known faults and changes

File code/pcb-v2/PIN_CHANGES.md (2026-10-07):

# Pin changes (PCB rework)

What changed between the V1 and V2 boards. The pin moves were made in the PCB
editor and have been applied to `include/pod_config.hpp` and the copy in
`tools/tof_test/src/main.cpp`. Not yet tested on a built V2 board.

V1 firmware is commit `f138950` (`git checkout f138950`).

## All changes at a glance

Eight pins moved. Everything else is the same.

| Signal | V1 GPIO | V2 GPIO |
|---|---|---|
| Vertical encoder A | 1 | **40** |
| Vertical encoder B | 2 | **42** |
| Horizontal encoder A | 3 | **39** |
| Horizontal encoder B | 4 | **41** |
| RS-485 DE/RE | 21 | **7** |
| ToF EN, FRONT | 11 | **4** |
| ToF EN, REAR | 14 | **1** |
| ToF EN, LEFT | 13 | **2** |

Unchanged: IMU RX 8, RS-485 TX/RX 17/18, I2C SDA/SCL 16/15, ToF EN RIGHT 12.

### V1 and V2 firmware are NOT interchangeable

Some GPIO numbers changed job, so flashing the wrong firmware drives the wrong
wire:

| GPIO | On V1 | On V2 |
|---|---|---|
| 1 | vertical encoder A (input) | ToF EN, REAR (output) |
| 2 | vertical encoder B (input) | ToF EN, LEFT (output) |
| 4 | horizontal encoder B (input) | ToF EN, FRONT (output) |
| 3 | horizontal encoder A | unused |
| 21 | RS-485 DE | unused |
| 11, 13, 14 | ToF EN | unused |

Always flash V2 firmware on the V2 board and V1 firmware on the V1 board.

Board: ESP32-S3-DevKitC-1, **N8R8** module. GPIO33-37 are wired to the octal
PSRAM inside the module and must not be used.

## Encoders

Moved from GPIO1-4 to GPIO39-42, four adjacent pins on header J3 (pins 6-9).

The converter (SN74LVC245A) is wired so B1/B2 carry the encoders' **B**
channels and B3/B4 carry their **A** channels, to make the wiring easier.
Each converter pin passes straight across to its partner (A1 <-> B1, etc.).

| Converter pin | Encoder wire | ESP32 GPIO | Header pin | Old GPIO |
|---|---|---|---|---|
| B1 | Vertical **B** | 42 | J3_6 | 2 |
| B2 | Horizontal **B** | 41 | J3_7 | 4 |
| B3 | Vertical **A** | 40 | J3_8 | 1 |
| B4 | Horizontal **A** | 39 | J3_9 | 3 |

Assumes DIR is tied high (A side -> B side): encoders on A1-A4, ESP32 on B1-B4.
If DIR is tied low, swap the sides.

### Code change (applied)

```cpp
constexpr int kVertEncAPin  = 40;
constexpr int kVertEncBPin  = 42;
constexpr int kHorizEncAPin = 39;
constexpr int kHorizEncBPin = 41;
```

If an encoder counts backwards after this, its A and B are swapped: flip
`kVertReversed` / `kHorizReversed` rather than rewiring.

## ToF sensors

FRONT, REAR and LEFT sensor EN moved to GPIO4, GPIO1 and GPIO2, which the
encoders freed up. GPIO11, GPIO13 and GPIO14 are now unused. (GPIO21 was
considered for LEFT but was RS-485 DE at the time; GPIO19 is native USB D-.)

| Signal | Old GPIO | New GPIO |
|---|---|---|
| EN, FRONT (tof0)  | 11 | 4 |
| EN, REAR (tof2) | 14 | 1 |
| EN, LEFT (tof3) | 13 | 2 |

### Code change (applied)

`include/pod_config.hpp` and `tools/tof_test/src/main.cpp`:

```cpp
constexpr int kTofEnPins[4] = {4, 12, 1, 2};
```

## RS-485 link

DE (tied to RE on the SP3485) moved to GPIO7 on the left header (J1), with
TX/RX on 17/18. It is the nearest free non-strapping pin: 15/16 between them
are I2C. GPIO21 is now unused. TX and RX are unchanged.

| Signal | Old GPIO | New GPIO |
|---|---|---|
| RS-485 DE/RE (SP3485) | 21 | 7 |

### Code change (applied)

`include/pod_config.hpp`:

```cpp
constexpr int kRs485DePin = 7;
```

## Unchanged

| Signal | GPIO |
|---|---|
| IMU RX (BNO085) | 8 |
| RS-485 TX / RX | 17 / 18 |
| I2C SDA / SCL | 16 / 15 |
| ToF EN RIGHT | 12 |

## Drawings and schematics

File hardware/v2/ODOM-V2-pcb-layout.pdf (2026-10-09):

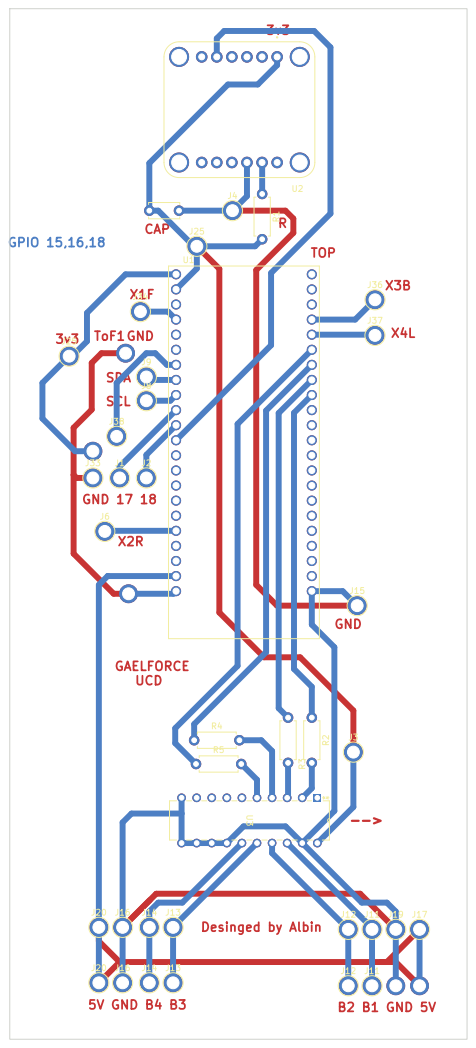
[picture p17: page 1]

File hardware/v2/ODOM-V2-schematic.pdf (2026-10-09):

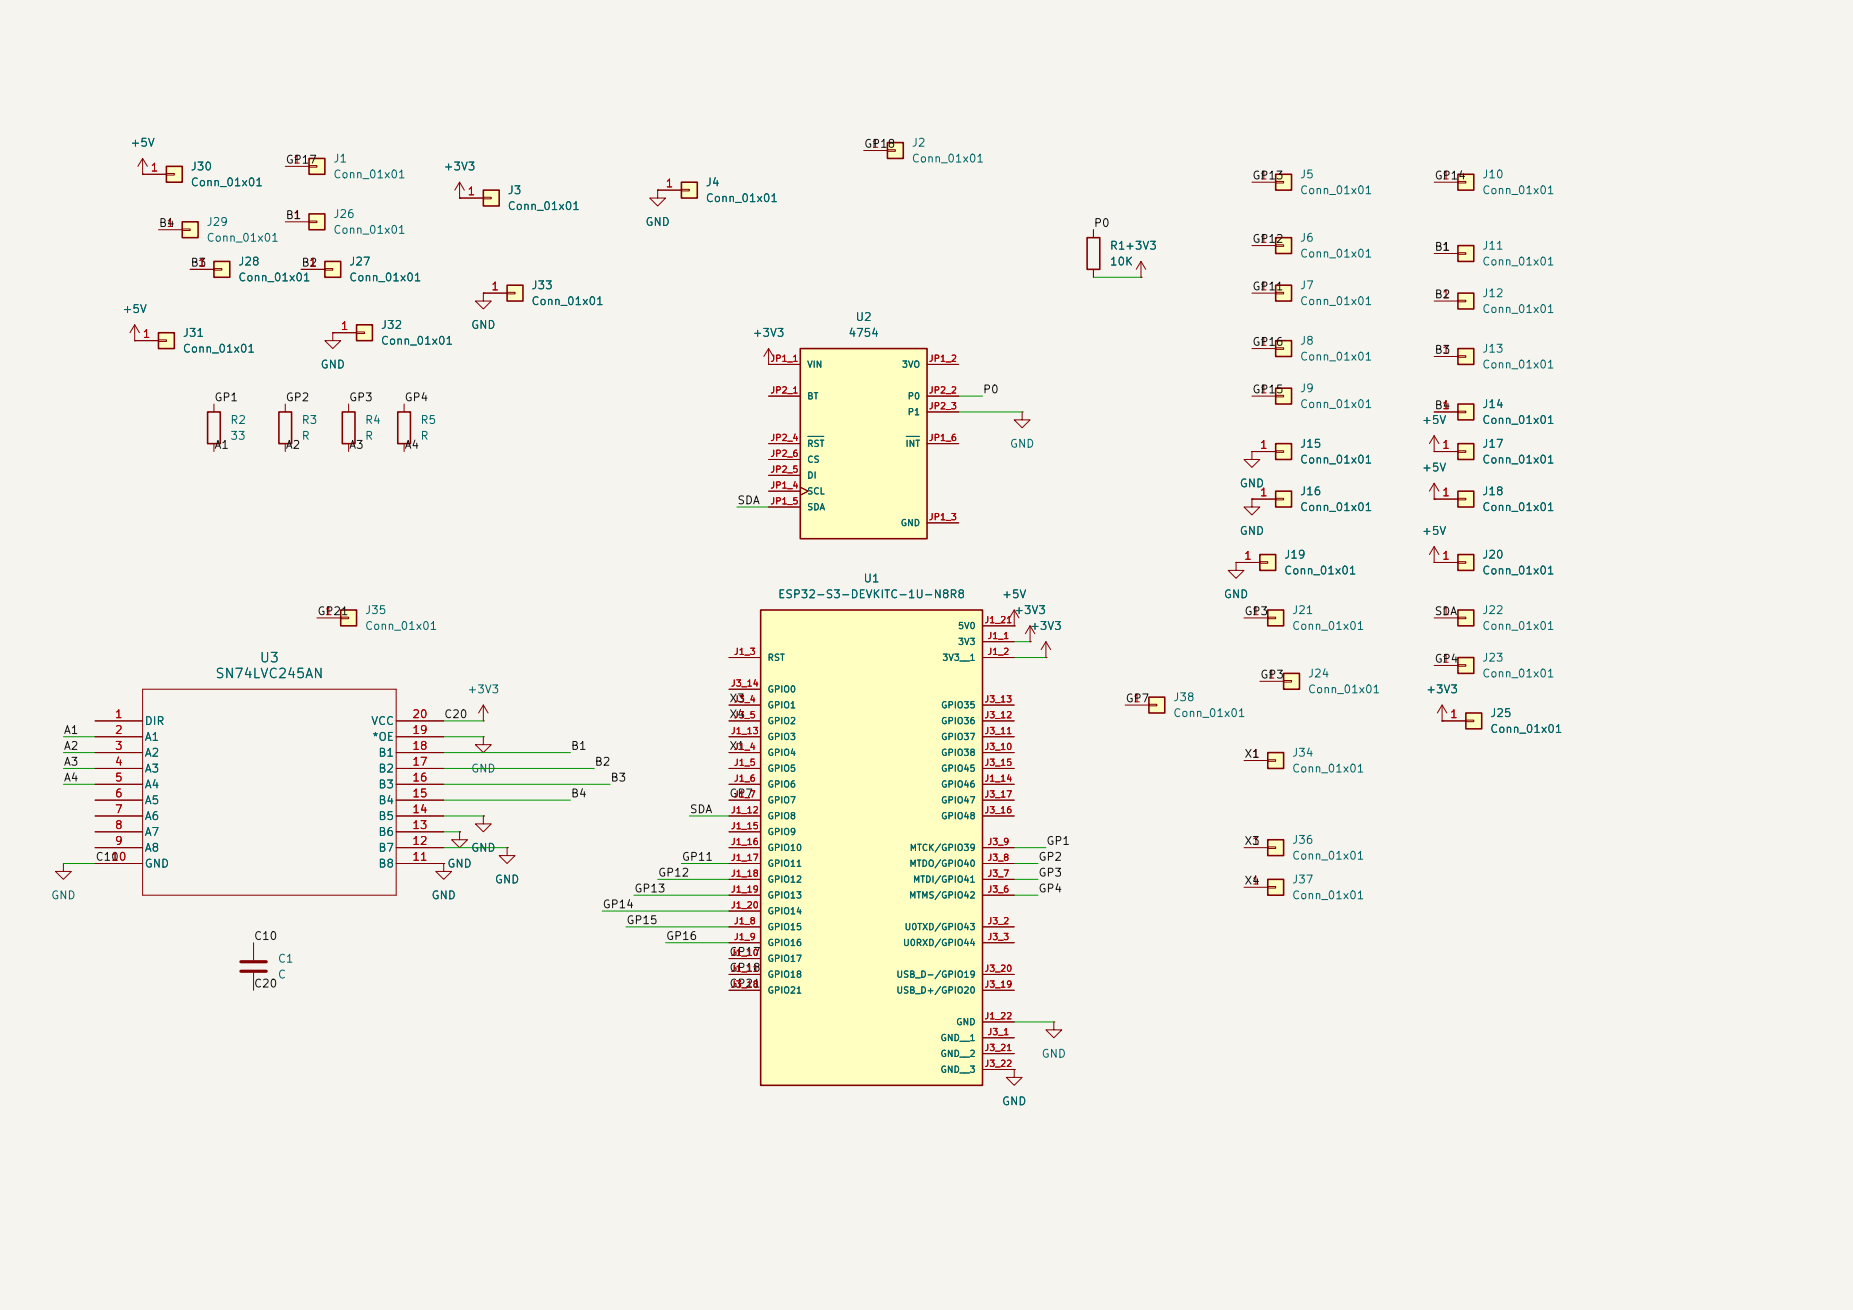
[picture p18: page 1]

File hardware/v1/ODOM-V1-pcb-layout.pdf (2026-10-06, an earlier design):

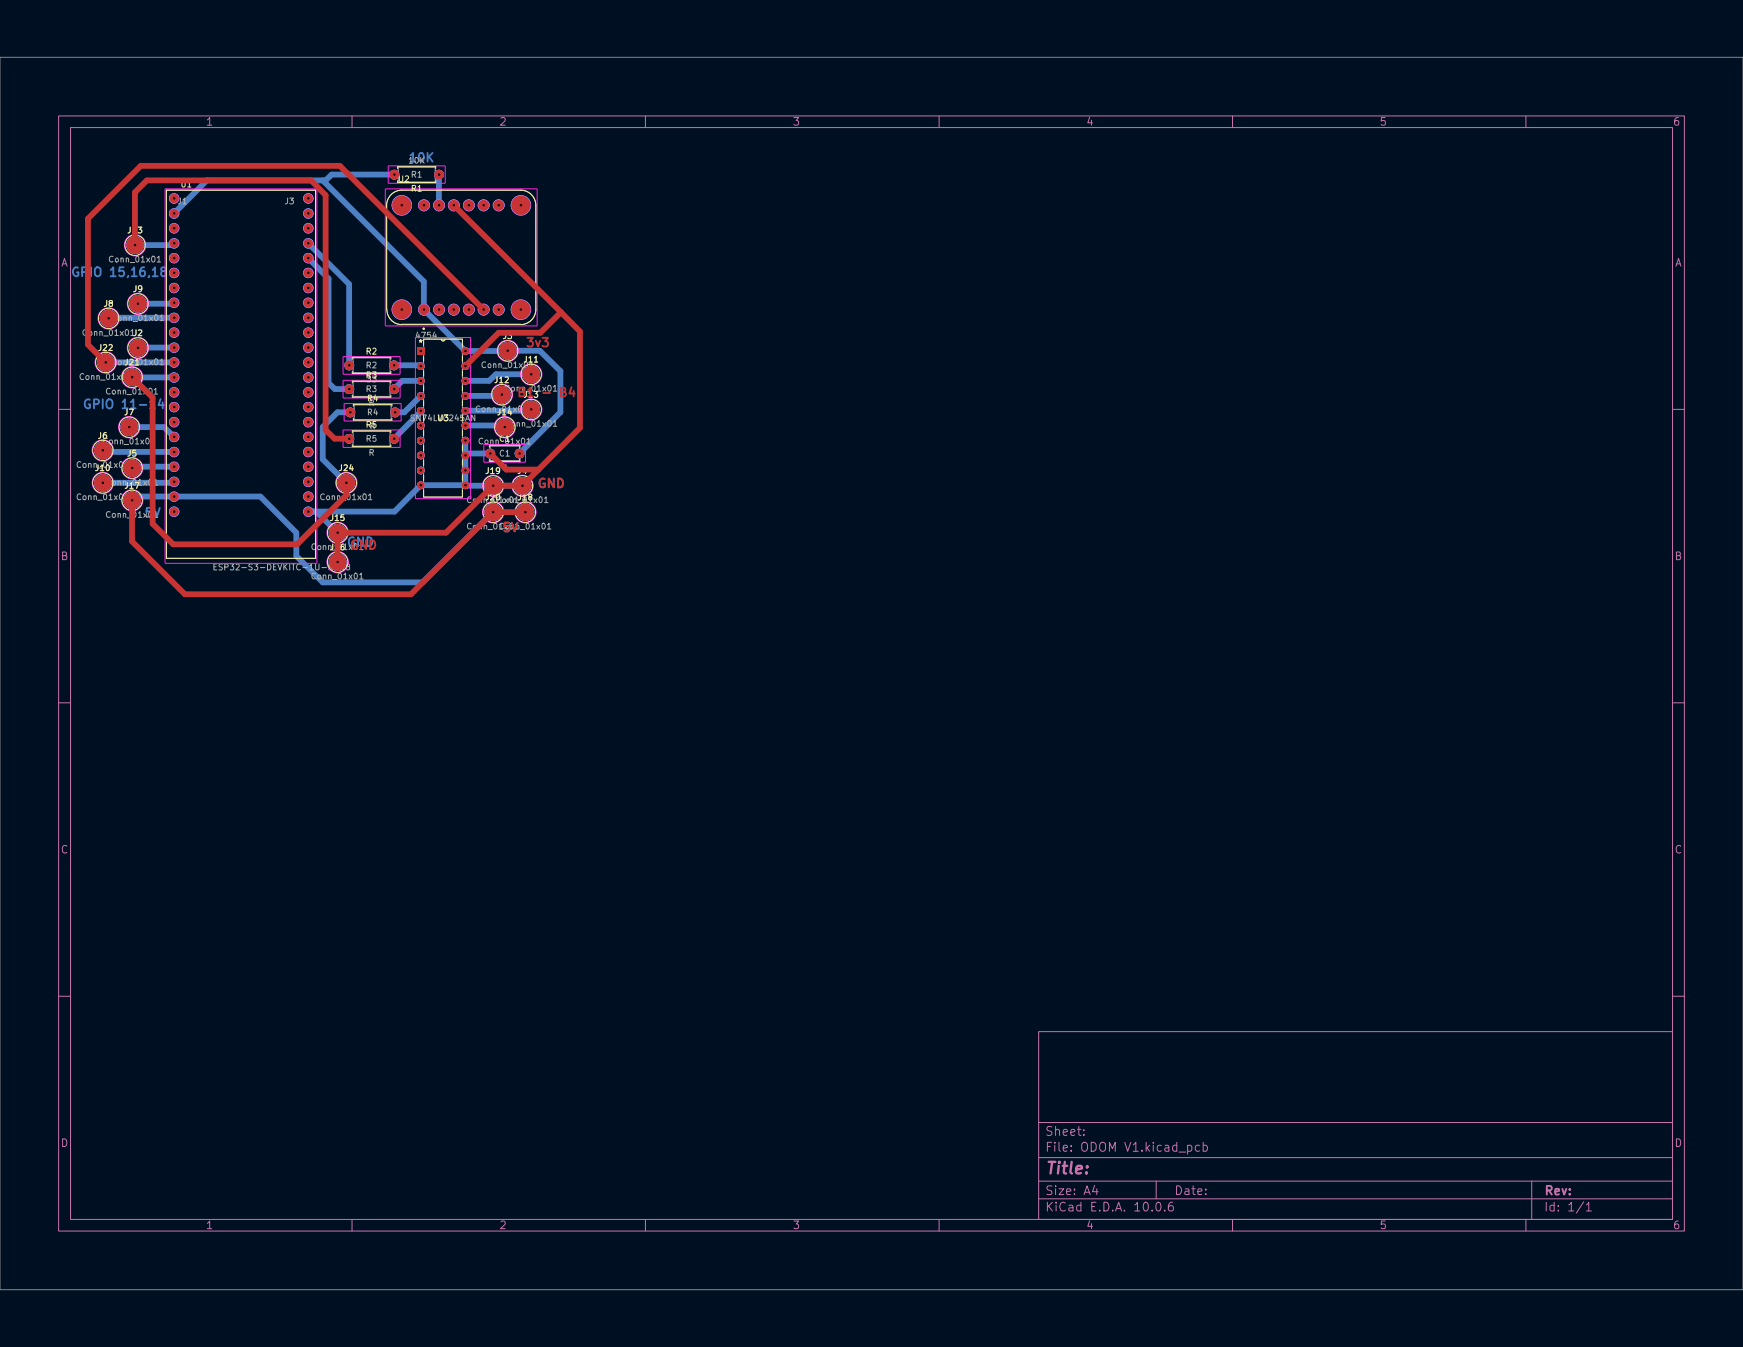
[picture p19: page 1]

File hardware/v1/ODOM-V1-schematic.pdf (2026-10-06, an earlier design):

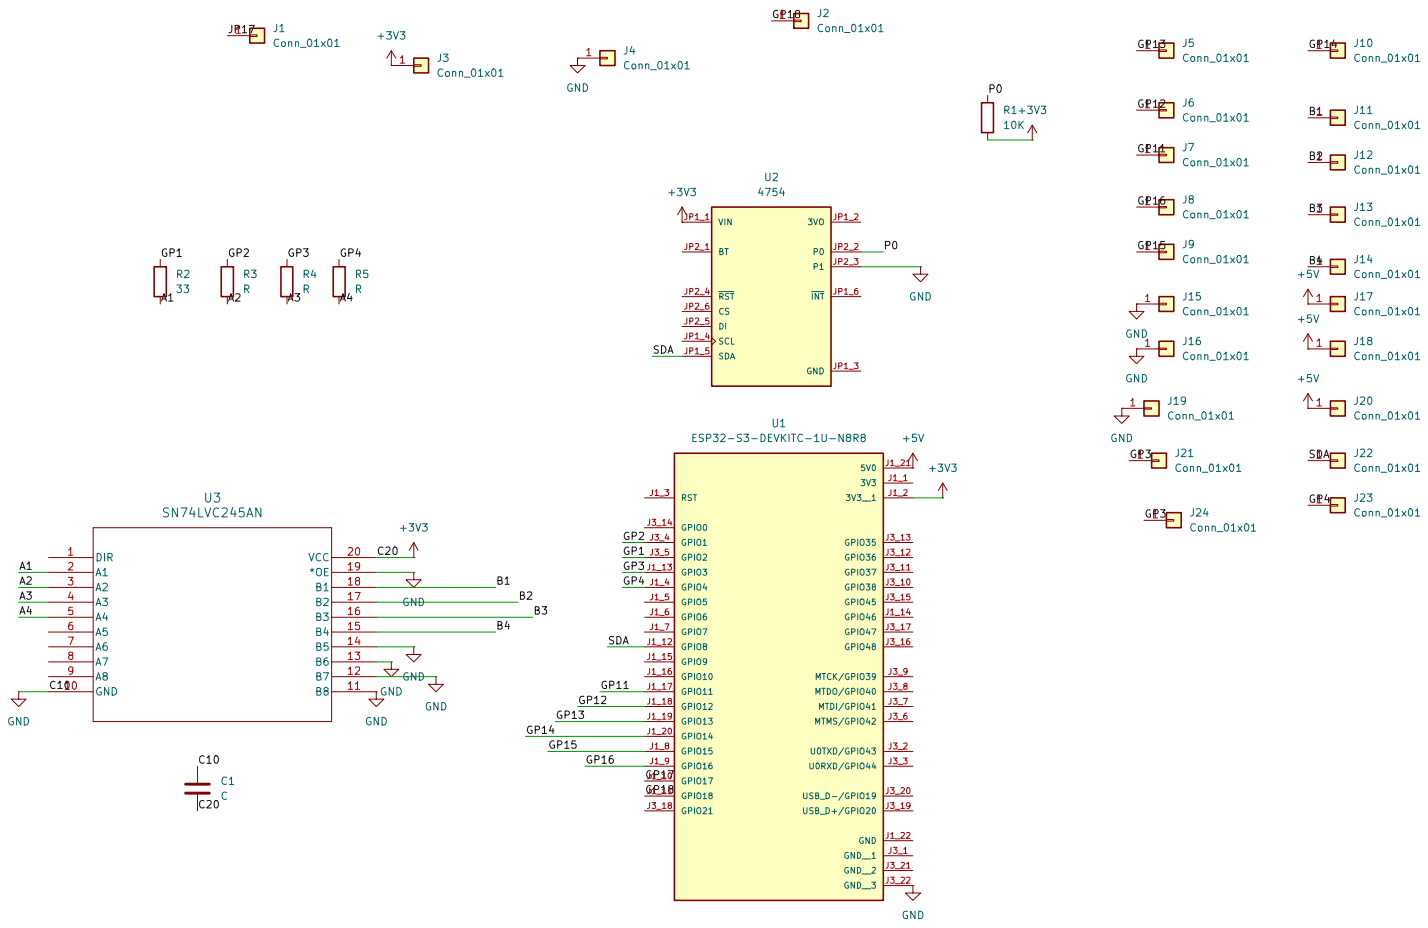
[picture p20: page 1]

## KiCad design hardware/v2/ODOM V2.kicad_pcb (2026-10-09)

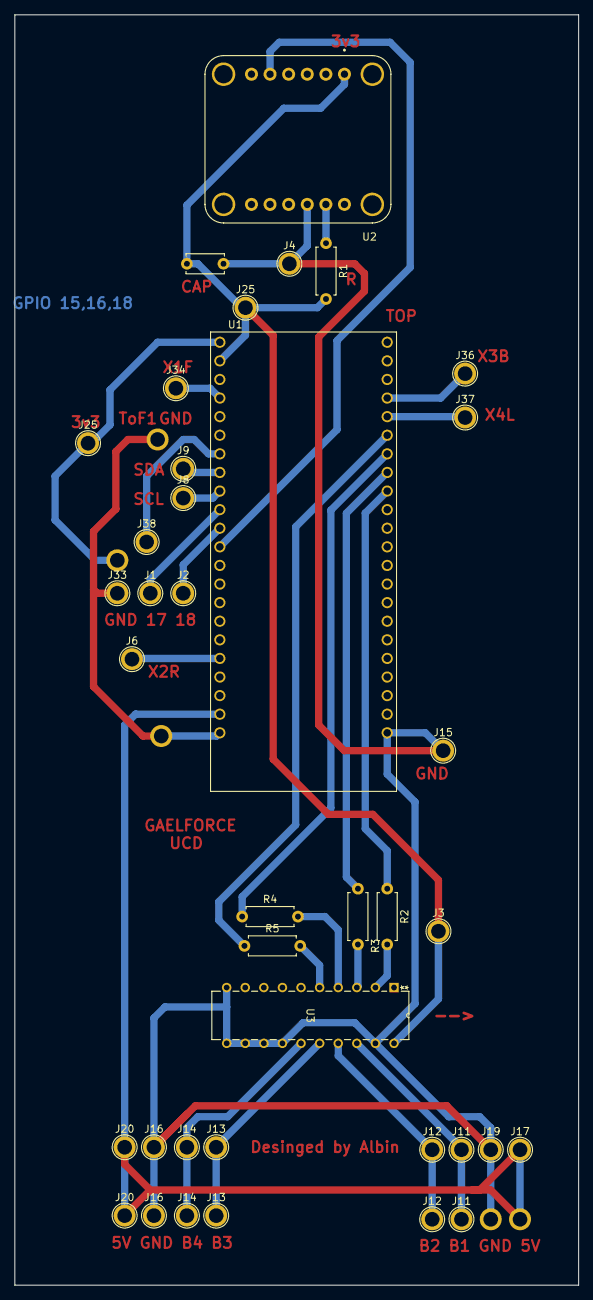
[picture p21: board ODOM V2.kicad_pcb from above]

Board: 2 copper layers, 77.0 x 173.5 mm, 38 parts (0 on the bottom side), 26 nets.

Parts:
C1: C; C_Disc_D5.0mm_W2.5mm_P5.00mm
J1, J2, J3, J4, J6, J8, J9, J11, J11#2, J12, J12#2, J13, J13#2, J14, J14#2, J15, J16, J16#2, J17, J19, J20, J20#2, J25, J25#2, J33, J34, J36, J37, J38: Conn_01x01; TestPoint_Plated_Hole_D2.0mm
R1: 10K; R_Axial_DIN0207_L6.3mm_D2.5mm_P7.62mm_Horizontal
R2: 33; R_Axial_DIN0207_L6.3mm_D2.5mm_P7.62mm_Horizontal
R3, R4, R5: R; R_Axial_DIN0207_L6.3mm_D2.5mm_P7.62mm_Horizontal
U1: ESP32-S3-DEVKITC-1U-N8R8; MODULE_ESP32-S3-DEVKITC-1U-N8R8
U2: 4754; MODULE_4754
U3: SN74LVC245AN; N20

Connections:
+3V3: C1.2, J3.1 (Pin_1_1), J25.1 (Pin_1_1), J25#2.1 (Pin_1_1), R1.2, U1.J1_1 (3V3), U1.J1_2 (3V3__1), U2.JP1_1 (VIN), U3.20 (VCC)
+5V: J17.1 (Pin_1_1), J20.1 (Pin_1_1), J20#2.1 (Pin_1_1), U1.J1_21 (5V0)
/A1: R2.2, U3.2 (A1)
/A2: R3.2, U3.3 (A2)
/A3: R4.2, U3.4 (A3)
/A4: R5.2, U3.5 (A4)
/B1: J11.1 (Pin_1_1), J11#2.1 (Pin_1_1), U3.18 (B1)
/B2: J12.1 (Pin_1_1), J12#2.1 (Pin_1_1), U3.17 (B2)
/B3: J13.1 (Pin_1_1), J13#2.1 (Pin_1_1), U3.16 (B3)
/B4: J14.1 (Pin_1_1), J14#2.1 (Pin_1_1), U3.15 (B4)
/GP1: R2.1, U1.J3_9 (MTCK/GPIO39)
/GP2: R3.1, U1.J3_8 (MTDO/GPIO40)
/GP3: R4.1, U1.J3_7 (MTDI/GPIO41)
/GP4: R5.1, U1.J3_6 (MTMS/GPIO42)
/GP7: J38.1 (Pin_1_1), U1.J1_7 (GPIO7)
/GP12: J6.1 (Pin_1_1), U1.J1_18 (GPIO12)
/GP15: J9.1 (Pin_1_1), U1.J1_8 (GPIO15)
/GP16: J8.1 (Pin_1_1), U1.J1_9 (GPIO16)
/GP17: J1.1 (Pin_1_1), U1.J1_10 (GPIO17)
/GP18: J2.1 (Pin_1_1), U1.J1_11 (GPIO18)
/P0: R1.1, U2.JP2_2 (P0)
/SDA: U1.J1_12 (GPIO8), U2.JP1_5 (SDA)
/X1: J34.1 (Pin_1_1), U1.J1_4 (GPIO4)
/X3: J36.1 (Pin_1_1), U1.J3_4 (GPIO1)
/X4: J37.1 (Pin_1_1), U1.J3_5 (GPIO2)
GND: C1.1, J4.1 (Pin_1_1), J15.1 (Pin_1_1), J16.1 (Pin_1_1), J16#2.1 (Pin_1_1), J19.1 (Pin_1_1), J33.1 (Pin_1_1), U1.J1_22 (GND), U1.J3_22 (GND__3), U2.JP2_3 (P1), U3.10 (GND), U3.11 (B8), U3.12 (B7), U3.13 (B6), U3.14 (B5), U3.19 (*OE)

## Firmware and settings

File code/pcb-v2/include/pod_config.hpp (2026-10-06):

#pragma once
#include "gflib/posesource.hpp"
#include "gflib/util.hpp"
#include "gflib/link.hpp"
#include "gflib/mcl.hpp"
#include "tmf8821.hpp"

// Every number that describes this particular robot lives in this file.
// Nothing below it knows a pin number or a wheel diameter, so retuning the
// machine never means reading the driver code.

namespace cfg {

using gflib::real;
using gflib::operator""_r;

// pins
//
// Unavailable on this board and deliberately absent below: 0/45/46 strapping,
// 19/20 USB, 26-32 SPI flash, 33-37 the octal PSRAM die -- the N8R8 module
// bonds those whether or not the software enables PSRAM -- and 48 the RGB LED.
// 43/44 are the console UART. That leaves 1-18, 21, 38-42.

// Quadrature pods, through the SN74LVC245A. The 245 drives actively, so the
// PCNT channels' default pull-ups are along for the ride and harmless.
constexpr int kVertEncAPin  = 40;
constexpr int kVertEncBPin  = 42;
constexpr int kHorizEncAPin = 39;
constexpr int kHorizEncBPin = 41;

// BNO085 UART-RVC. RX only: RVC is one-way and the part accepts nothing back.
// The P0 jumper on the breakout must be bridged or it comes up in I2C mode
// and this pin stays silent forever -- indistinguishable from a broken wire.
constexpr int kImuRxPin = 8;

// SP3485. DE and RE are tied together and driven as UART RTS, which lets
// uart_set_mode(UART_MODE_RS485_HALF_DUPLEX) handle the turnaround in
// hardware. Doing it from software is the classic RS-485 bug: release a bit
// early and the last byte is truncated, a bit late and it stamps on the reply.
constexpr int kRs485TxPin = 17;
constexpr int kRs485RxPin = 18;
constexpr int kRs485DePin = 7;


constexpr int kI2cSdaPin = 16;
constexpr int kI2cSclPin = 15;
// Harness order, not numeric order
// The array is indexed by TofIndex alongside kTofAddrs and kTofMounts
// the wiring is absorbed here rather than by renumbering the enum.
constexpr int kTofEnPins[4] = {4, 12, 1, 2};

// encoders

// AMT102-V, switch-selected to 2048 PPR. Full quadrature counts all four
// edges of each cycle, so a revolution is 4x the PPR. Getting this wrong
// scales every distance by exactly 4, which reads as a plausible calibration
// error rather than a bug.
constexpr real kCountsPerRev = 8192.0_r;

// PLACEHOLDER, not a measurement. Nothing downstream is trustworthy until
// this is the real wheel.
constexpr real kTrackingWheelDiaIn = 2.0_r;

constexpr bool kVertReversed  = false;
constexpr bool kHorizReversed = false;

// Well under the shortest real edge: at the placeholder 2in wheel, 5ft/s is
// an edge every ~13us. Also under the peripheral's own ~12.7us ceiling.
constexpr uint32_t kEncoderGlitchFilterNs = 1000;

// The hardware counter is 16-bit signed. The driver accumulates past these
// only if watch points sit exactly on them -- see PcntEncoder::begin.
constexpr int kPcntHighLimit =  32000;
constexpr int kPcntLowLimit  = -32000;

// odom geometry

// Confirmed: the pods are mounted as a diamond, not forward/sideways.
constexpr real kPodAngleDeg = 45.0_r;

// PLACEHOLDERS. Signed perpendicular distances from the tracking centre --
// the sign matters as much as the magnitude, because a sign error injects
// rotation into the pose as though it were travel.
constexpr real kVertOffsetIn  = 3.0_r;
constexpr real kHorizOffsetIn = 3.0_r;

inline gflib::OdomSourceConfig makeOdom() {
    gflib::OdomSourceConfig c;

    c.odom.podAngleDeg = kPodAngleDeg;
    c.odom.vertOffsetInches = kVertOffsetIn;
    c.odom.horizOffsetInches = kHorizOffsetIn;

    const real inchesPerCount = gflib::kPi * kTrackingWheelDiaIn / kCountsPerRev;
    c.odom.vertInchesPerCount = inchesPerCount;
    c.odom.horizInchesPerCount = inchesPerCount;

    return c;
}

// loop and link

constexpr uint32_t kLoopPeriodMs = 10;

// Spent draining the RX line after the pose frame goes out
constexpr int64_t kRxWindowUs = 8000;

constexpr int64_t kRxWindowIdleUs = 1000;

// Three missed replies. The Brain sends one per pose frame, so this is a link
// that has actually stopped rather than one that dropped a frame.
constexpr uint32_t kBrainStatusTimeoutMs = 30;

// IMU timeout, if longer than this then likely dead connection
constexpr uint32_t kImuFrameTimeoutMs = 50;

// 8N1 on the wire is one start bit, eight data, one stop.
constexpr real kBitsPerSerialByte = 10.0_r;

// Air time is exactly computable and must be subtracted from a round trip
// before halving it: the pose frame is 56 bytes and the status reply 23, so
// splitting the raw figure evenly biases the result by most of a millisecond.
inline real airTimeMs(size_t bytes) {
    return (static_cast<real>(bytes) * kBitsPerSerialByte * 1000.0_r)
           / static_cast<real>(gflib::kLinkBaud);
}

// ToF sensors

// Indices must match SensorReading::mountIndex.
enum TofIndex : int { kTofFront = 0, kTofRight = 1, kTofRear = 2, kTofLeft = 3 };
constexpr int kTofCount = 4;

// All TMF8821s boot at volatile address 0x41.
constexpr uint8_t kTofBootAddr = 0x41;
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

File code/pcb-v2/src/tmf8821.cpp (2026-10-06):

#include "tmf8821.hpp"

#include <cstring>

#include "driver/gpio.h"
#include "esp_check.h"
#include "esp_timer.h"
#include "freertos/FreeRTOS.h"
#include "freertos/task.h"
#include "tof_firmware.hpp"

namespace tof {

namespace {

const char* kTag = "tof";

// registers -- DS000693 section 8
constexpr uint8_t kRegAppId        = 0x00;
constexpr uint8_t kRegMinor        = 0x01;
constexpr uint8_t kRegCalibStatus  = 0x07;
constexpr uint8_t kRegCmdStat      = 0x08;
constexpr uint8_t kRegConfigResult = 0x20;   // cid_rid, then tid, size
constexpr uint8_t kRegPeriodMs     = 0x24;
constexpr uint8_t kRegKiloIter     = 0x26;
constexpr uint8_t kRegConfThresh   = 0x30;
constexpr uint8_t kRegSpadMapId    = 0x34;
constexpr uint8_t kRegI2cAddr      = 0x3B;
constexpr uint8_t kRegI2cAddrChg   = 0x3E;
constexpr uint8_t kRegEnable       = 0xE0;
constexpr uint8_t kRegIntStatus    = 0xE1;
constexpr uint8_t kRegIntEnab      = 0xE2;

// application ids
constexpr uint8_t kAppMeasure    = 0x03;
constexpr uint8_t kAppBootloader = 0x80;

// commands written to CMD_STAT
constexpr uint8_t kCmdMeasure         = 0x10;
constexpr uint8_t kCmdWriteConfigPage = 0x15;
constexpr uint8_t kCmdLoadCommonPage  = 0x16;
constexpr uint8_t kCmdLoadSpadPage1   = 0x17;
constexpr uint8_t kCmdI2cAddress      = 0x21;
constexpr uint8_t kCmdStop            = 0xFF;

// Pending while CMD_STAT reads >= 0x10; below that it is a status.
constexpr uint8_t kStatusOk       = 0x00;
constexpr uint8_t kStatusAccepted = 0x01;
constexpr uint8_t kStatusPending  = 0x10;

// bootloader commands -- AN001015 section 3
constexpr uint8_t kBlRamRemapReset = 0x11;
constexpr uint8_t kBlDownloadInit  = 0x14;
constexpr uint8_t kBlWriteRam      = 0x41;
constexpr uint8_t kBlSetAddr       = 0x43;
constexpr uint8_t kBlChunkBytes    = 128;

// cid_rid values for the paged window at 0x24..0xDF
constexpr uint8_t kPageMeasureResult = 0x10;
constexpr uint8_t kPageCommonConfig  = 0x16;
constexpr uint8_t kPageSpad1         = 0x17;

// SPAD_ENABLE 0x24-0x41, SPAD_TDC 0x42-0x8C, then offsets and sizes 0x8D-0x90.
constexpr uint8_t kRegSpadPageBase   = 0x24;
constexpr size_t  kSpadPageBytes     = 0x90 - 0x24 + 1;

// INT_STATUS bit 1 -- measurement result ready. Write-1-to-clear.
constexpr uint8_t kIntResult = 0x02;

// ENABLE bits: cpu_ready (6) and pon (0).
constexpr uint8_t kEnableCpuReady = 0x40;
constexpr uint8_t kEnablePon      = 0x01;

// cid_rid at 0x20, then the header, then 3 bytes per zone from 0x38.
constexpr uint8_t kResultBase  = kRegConfigResult;
constexpr size_t  kZoneBase    = 0x38 - kResultBase;

// Stop after kZonesRead; the zones past it are bus time nothing consumes.
constexpr size_t  kResultBytes = kZoneBase + 3 * kZonesRead;

constexpr int kXferTimeoutMs = 100;

// EN must stay low ≥1 ms to force a cold start (AN001015 §2).
constexpr uint32_t kResetHoldMs = 5;

// ACK-poll deadline after power-on.
constexpr uint32_t kAckTimeoutMs = 50;

// Every un-enumerated part answers here -- hence one at a time.
constexpr uint16_t kBootAddress = 0x41;

// One's complement of CMD_STAT + SIZE + data.
uint8_t blChecksum(const uint8_t* p, size_t n) {
    uint32_t sum = 0;
    for (size_t i = 0; i < n; ++i) sum += p[i];
    return static_cast<uint8_t>(~sum);
}

uint32_t le32(const uint8_t* p) {
    return static_cast<uint32_t>(p[0]) | (static_cast<uint32_t>(p[1]) << 8) |
           (static_cast<uint32_t>(p[2]) << 16) | (static_cast<uint32_t>(p[3]) << 24);
}

bool expired(int64_t startUs, uint32_t timeoutMs) {
    return (esp_timer_get_time() - startUs) > static_cast<int64_t>(timeoutMs) * 1000;
}

}  // namespace

Tmf8821::Tmf8821(int enPin, uint8_t runAddr) : enPin_(enPin), runAddr_(runAddr) {}

// i2c primitives

esp_err_t Tmf8821::wr(uint8_t reg, const uint8_t* data, size_t n) {
    // One transaction: a STOP between register and payload loses the pointer.
    uint8_t buf[kBlChunkBytes + 8];
    if (n + 1 > sizeof(buf)) return ESP_ERR_INVALID_SIZE;
    buf[0] = reg;
    if (n) std::memcpy(buf + 1, data, n);

    const esp_err_t e = i2c_master_transmit(dev_, buf, n + 1, kXferTimeoutMs);
    if (e != ESP_OK) ++busErrors_;
    return e;
}

esp_err_t Tmf8821::wr8(uint8_t reg, uint8_t v) { return wr(reg, &v, 1); }

esp_err_t Tmf8821::rd(uint8_t reg, uint8_t* dst, size_t n) {
    const esp_err_t e =
        i2c_master_transmit_receive(dev_, &reg, 1, dst, n, kXferTimeoutMs);
    if (e != ESP_OK) ++busErrors_;
    return e;
}

esp_err_t Tmf8821::rd8(uint8_t reg, uint8_t& v) { return rd(reg, &v, 1); }

// Deadline polling

esp_err_t Tmf8821::waitCpuReady(uint32_t timeoutMs) {
    const int64_t start = esp_timer_get_time();
    for (;;) {
        uint8_t v = 0;
        if (rd8(kRegEnable, v) == ESP_OK &&
            (v & kEnableCpuReady) && (v & kEnablePon)) {
            return ESP_OK;
        }
        if (expired(start, timeoutMs)) return ESP_ERR_TIMEOUT;
        vTaskDelay(pdMS_TO_TICKS(1));
    }
}

esp_err_t Tmf8821::waitCommand(uint8_t& status, uint32_t timeoutMs) {
    const int64_t start = esp_timer_get_time();
    for (;;) {
        uint8_t v = 0;
        if (rd8(kRegCmdStat, v) == ESP_OK && v < kStatusPending) {
            status = v;
            return ESP_OK;
        }
        if (expired(start, timeoutMs)) return ESP_ERR_TIMEOUT;
        vTaskDelay(pdMS_TO_TICKS(1));
    }
}

esp_err_t Tmf8821::waitBootloaderReady(uint32_t timeoutMs) {
    const int64_t start = esp_timer_get_time();
    for (;;) {
        // Completed command answers 00 00 FF: status 0, size 0, checksum.
        uint8_t v[3] = {};
        if (rd(kRegCmdStat, v, sizeof(v)) == ESP_OK &&
            v[0] == 0x00 && v[1] == 0x00 && v[2] == 0xFF) {
            return ESP_OK;
        }
        if (expired(start, timeoutMs)) return ESP_ERR_TIMEOUT;
        vTaskDelay(pdMS_TO_TICKS(1));
    }
}

esp_err_t Tmf8821::waitAppId(uint8_t want, uint32_t timeoutMs) {
    const int64_t start = esp_timer_get_time();
    for (;;) {
        uint8_t v = 0;
        if (rd8(kRegAppId, v) == ESP_OK && v == want) return ESP_OK;
        if (expired(start, timeoutMs)) return ESP_ERR_TIMEOUT;
        vTaskDelay(pdMS_TO_TICKS(1));
    }
}

// bring-up

esp_err_t Tmf8821::holdReset() {
    gpio_config_t c = {};
    c.pin_bit_mask = 1ULL << enPin_;
    c.mode = GPIO_MODE_OUTPUT;
    c.pull_up_en = GPIO_PULLUP_DISABLE;
    c.pull_down_en = GPIO_PULLDOWN_DISABLE;
    c.intr_type = GPIO_INTR_DISABLE;
    ESP_RETURN_ON_ERROR(gpio_config(&c), kTag, "en pin %d", enPin_);

    present_ = false;
    return gpio_set_level(static_cast<gpio_num_t>(enPin_), 0);
}
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

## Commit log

2026-10-06 Align component rationale with the breadboard firmware
    Note that the first build is single-task at 100 Hz, and that PSRAM is
    present on the module but deliberately disabled.
    Claude-Session: https://claude.ai/code/session_01FpuWj6u5XndqyRXr8qbKmK
2026-10-06 Add pin map, wiring notes and key settings to section 2
    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
2026-10-06 Add breadboard circuit diagrams to section 2
    Four wiring diagrams (encoders, IMU, ToF chain, RS-485) with stray UI
    overlays removed, plus a note that two differ from the flashed pin table.
    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
2026-10-06 Point section 2 at the breadboard commit f9613c0 and fix its pins
    The diagrams are right: horizontal encoder on GPIO 4/5 and ToF SDA/SCL on
    15/16. Later commits (pin change, ToF mask fix, bench test) are noted as
    not part of the breadboard build.
    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
2026-10-06 Record that the ToF sensors worked on the breadboard
    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
2026-10-06 Add section 3 draft: PCB V1
    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
2026-10-06 Add V1 KiCad design files and link them from PCB V1 section
    Adds hardware/v1 with the schematic, project file, custom libraries and
    Gerbers zip, plus a Design files section in docs/03-pcb-v1.md.
    Schematic PDF and board renders are not included yet.
    [ODOM V1.kicad_sch]
2026-10-06 Add Design files section to PCB V1 write-up
    Links the Gerbers zip and the hardware/v1 KiCad project folder.
2026-10-06 Show the V1 schematic in the PCB V1 section
    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
2026-10-06 Add 3D render of the V1 board to section 3
    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
2026-10-06 Add the V1 PCB layout to section 3
    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
2026-10-06 Add firmware snapshots and V1 build photos
    Copies the pod firmware at three commits (breadboard f9613c0, PCB V1
    f138950, PCB V2 d8f95ed) into code/, adds the V1 board and soldering
    photos to section 3, and lists the repo layout in the README.
    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
2026-10-07 Add section 4: PCB V2
    Covers the IMU ground fix, the smaller board and the pin changes.
    Refreshes the V2 firmware snapshot to 986a2f3 and updates section 3.
    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
2026-10-09 Add V2 KiCad design files, PDFs and previews to section 4
    Adds hardware/v2 (project, schematic, board, custom libraries with
    project-relative library tables), schematic and layout PDFs, and
    schematic, layout and 3D previews. Gerbers are not included yet.
    [ODOM V2.kicad_pcb, ODOM V2.kicad_sch]
2026-10-09 Use the angled KiCad 3D render for the V2 board
    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
2026-10-09 Use the KiCad PCB editor screenshot for the V2 layout
    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
2026-10-09 Add V2 Gerbers, drill files and job file
    [ODOM V2-job.gbrjob]
2026-10-09 Add a second V1 soldering photo to section 3
    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
2026-10-09 Add a photo of the made V2 board and update its status
    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
2026-10-09 Move the second soldering photo to section 4
    It shows the V2 board, not V1, so the V2 status no longer says the
    parts are not soldered on.
    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
2026-10-09 Mark section 4 as done and note V2 is soldered and awaiting tests
    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
2026-10-12 Add PCB V2 test results and what went wrong
    Claude-Session: https://claude.ai/code/session_011F9RBYMMFJeGtSQ2zV5iMB
